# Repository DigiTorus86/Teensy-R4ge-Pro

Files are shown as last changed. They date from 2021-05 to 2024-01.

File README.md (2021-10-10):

# Teensy-R4ge-Pro
<p>
Software and resources for the Teensy R4ge Pro custom game platform. See documents folder for schematic.  
</p>

<p>
Harness the power of the 600MHz ARM Cortex M-7 that powers the Teensy 4.1 with flexible controls, a large display, CD-quality sound input and output.  Runs a variety of emulators for a retro-tastic mobile arcade experience.  Works as a high-fidelity sound generating and processing platform.  Includes a 10dB booster circuit with gain control, suitable for applying digital effects to a variety of audio input sources - including electric guitars.  
</p>

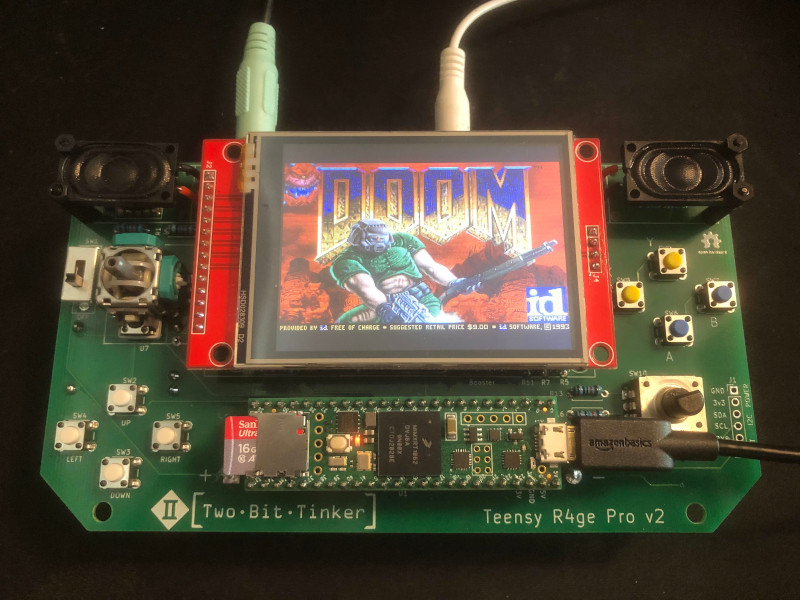
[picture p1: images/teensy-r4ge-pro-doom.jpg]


<h3>Key Components/Requirements</h3>
<p>
- Custom PCB, bread board, or protoboard.  See the gerbers folder or order from https://www.pcbway.com/project/shareproject/Teensy_4_1_R4ge_Pro_Mobile_Platform.html <br>
- Teensy 4.1<br>
- ILI9341 320x240 TFT with touch screen<br>
- Analog joystick<br>
- Rotary encoder<br>
- PCM5102a I2S DAC w/headphone jack<br>
- PAM8403 amplifier and 8 Ohm/1W speakers and/or powered external speakers w/3.5mm jack<br>
- PCM1802 I2S Stereo ADC<br>
- TL072 OpAmp<br>
- 8 MB PSRAM, SD card, and USB host cable for Teensy strongly recommended, as these are required to run different platform emulators<br>
- Some sketches have additional hardware requirements (components attached to I2C or Serial pins, or SD card)<br>
- See BOM file in the documents folder for full list of components.<br>
- STL file for printing a simple case also included in the documents folder.<br>
</p>

<p>
  Runs Doom and the other MCUME emulators by Jean MarcHarvengt.    https://github.com/Jean-MarcHarvengt/MCUME
  Requires minor config and IO pin mapping changes, as well as 8MB PSRAM and an SD card.  
</p>

<h3>App Descriptions</h3>
<p>
  - Test:   Exercises all the hardware on the board to verify operation and calibration. <br/>
  - Gravitack: Classic vector space shooter. (Port from original ESP32 Conference Badge)  <br/>
  - Tombstone: Port of the classic TI-99/4A game.  <br/>
  - Synth:  A graphical 4-operator/4-voice FM synth, playable via on-screen keyboard + stylus, 8 step sequencer, or MIDI input on the RX8 pin.<br/>
</p>

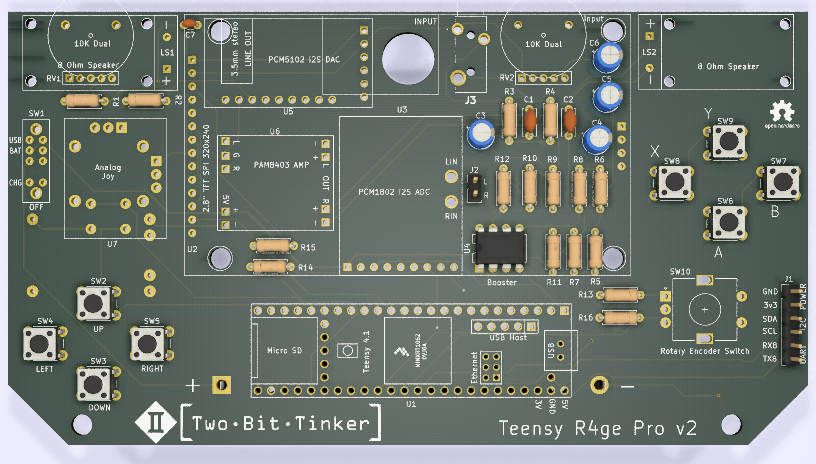
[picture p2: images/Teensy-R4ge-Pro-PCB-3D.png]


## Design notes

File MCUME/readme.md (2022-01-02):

### Using MCUME on the Teensy R4ge Pro

1. Install the 8MB PSRAM chip on the bottom of your Teensy 4.1.  Purchase link, instructions, and test app can be found at https://www.pjrc.com/store/psram.html 
2. Make sure you have a FAT32 formatted micro SD available.
3. Having the USB pins soldered to the Teensy and hooked up to a USB keyboard is very helpful as some games/options require keyboard input to proceed.  Can purchase the USB host cable from https://www.pjrc.com/store/cable_usb_host_t36.html   
3. Clone the MCUME repo: https://github.com/Jean-MarcHarvengt/MCUME/ 
4. Create the directories in the root of the SD card for the emulator ROM files and copy your ROM files to them.  Place the microSD in the Teensy's built-in SD card slot.
5. Copy the iopins.h and platform_config.h files from the Teensy-R4ge-Pro folders (or copy/paste the settings) to set the correct hardware configuration for each emulator.
6. Load the sketch for the emulator you want to run into the Arduino IDE.
7. Select Tools->Optimize and choose the appropriate option based on the emulator.
    - Doom:  Faster
    - Castaway/Atari ST:  Smallest Code
    - NES/Nofrendo:  Faster
    - UAE/Amiga:  Smallest Code
  
8. Compile and load the sketch to the Teensy.  If it works, you should see the game/emulator screen and be able to select from the list of detected ROMs that you loaded to the microSD. 

## Troubleshooting
- If compilation fails and exceeds available memory, try optimizing for Smallest Code
- If compiling on Mac or Linux, may need to fix some include file capitalization errors in MCUME (i.e. in tft_t_dma.cpp).
- Verify that the PSRAM is installed and working using the Teensy example sketch
- Hookup a keyboard to the Teensy USB pins and try different keypresses if screen appears frozen
- Try loading different ROMs.  Quite a few of the tested ROMs failed to work.
- Try the latest code from the MCUME repo or the included emulator code in this repo.

## Teensy R4ge Pro GPIO Pin Assignments

Full list of GIP pin assignments can be found in the ```teensy_r4ge_pro.h``` file in the Arduino IDE test sketch or any of the PlatformIO ```include``` folders.

- TFT_DC     9  // Data (high)/Command (low) pin
- TFT_CS    10  // SPI Chip Select pin for screen (active low)
- TFT_RST  255  // Reset pin NOT USED, connected to 3V3 (always high)
- TFT_MISO  12  // SPI Master In Slave Out
- TFT_MOSI  11  // SPI Master Out Slave In
- TFT_CLK   13  // SPI Clock
- TFT_LED  255  // TFT LED brightness control, connected to 3V3
- TCH_CS    37  // SPI Touch controller Chip Select (active low)
- SD_CS     BUILTIN_SDCARD  // (254) SPI SD card reader Chip Select pin

- JOYX_L    16  // Left analog joystick X axis
- JOYY_L    17  // Left analog joystick Y axis
- JBTN_L    25  // Left joystick button

- ENC_BTN  24  // Rotary encoder button/switch

- BTN_Y     5
- BTN_X     4
- BTN_B     3
- BTN_A     2
- BTN_RIGHT 32
- BTN_LEFT  31
- BTN_DOWN  30
- BTN_UP    29

Teensy 4.1 I2C Pins 
- SDA       18
- SCL       19

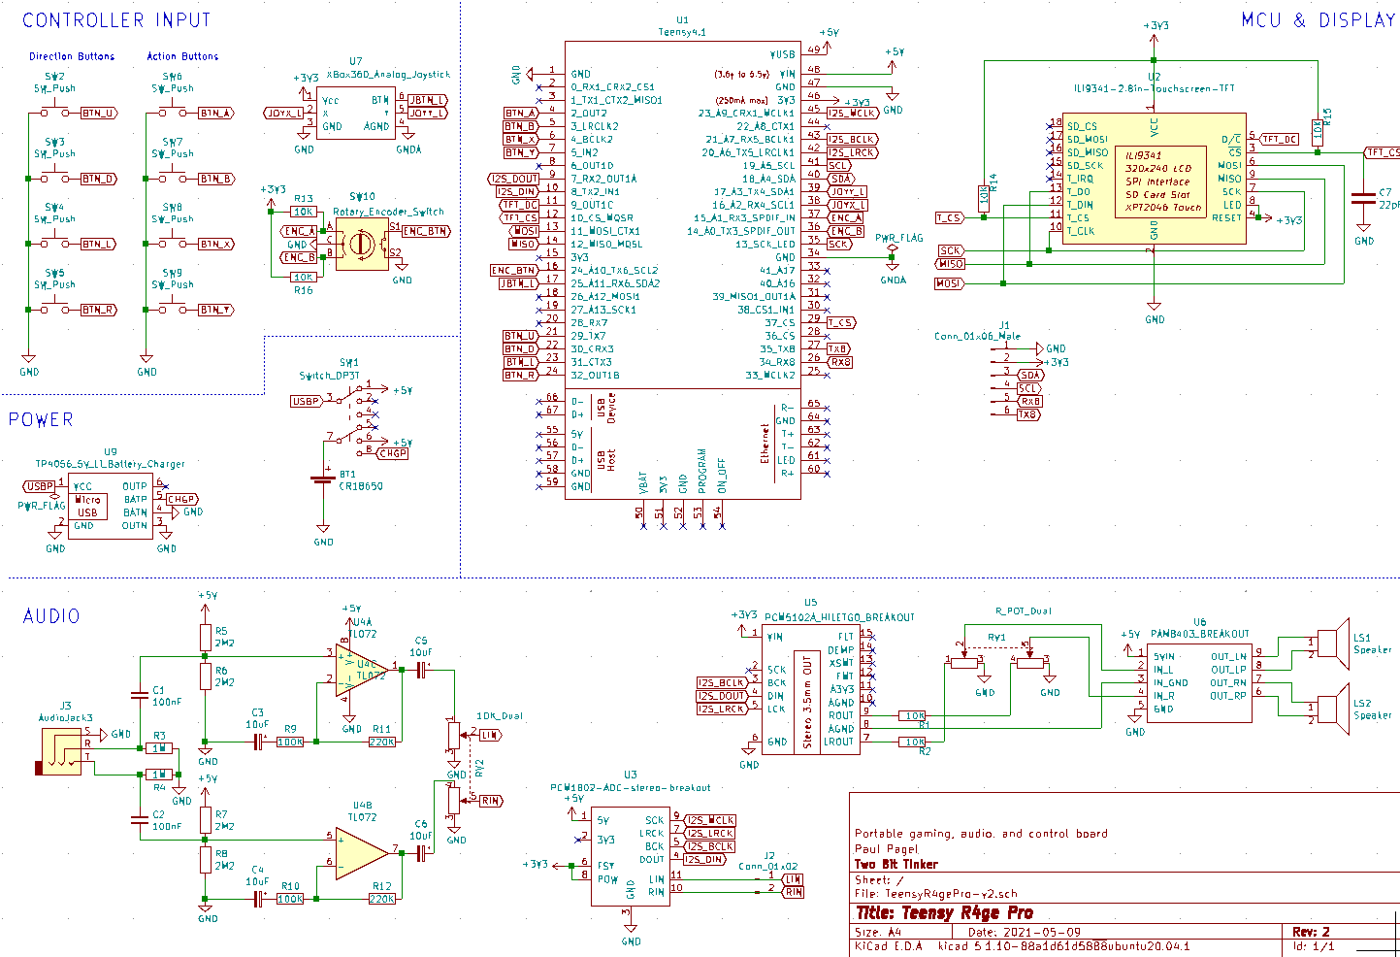
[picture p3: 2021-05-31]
images/Teensy-R4ge-Pro-schematic.png

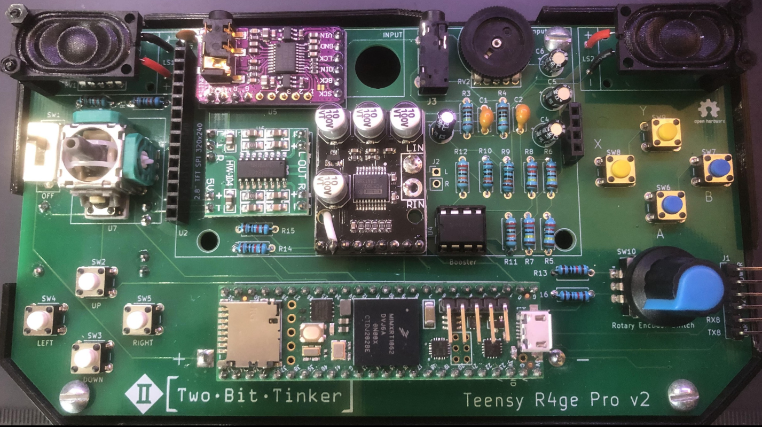
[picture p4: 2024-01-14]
images/Teensy-R4ge-Pro-no-screen.png

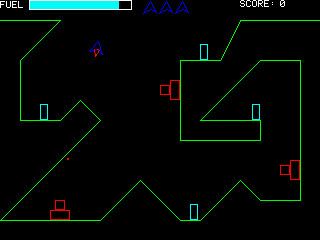
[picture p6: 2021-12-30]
images/Gravitack-L6.jpg

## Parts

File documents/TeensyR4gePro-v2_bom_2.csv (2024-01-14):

Component | Description | Part | References | Value | Footprint | Quantity Per PCB | Datasheet
1 | Single-cell battery | Battery_Cell | BT1 | CR18650 | BatteryHolder_MPD_BH-18650-PC2-no-holes | 1 | ~
2 | Unpolarized capacitor, small symbol | C_Small | C1 C2 | 100nF | C_Disc_D5.0mm_W2.5mm_P5.00mm | 2 | ~
3 | Polarized capacitor, small symbol | CP_Small | C3 C4 C5 C6 | 10uF | CP_Radial_D5.0mm_P2.50mm | 4 | ~
4 | Unpolarized capacitor | C | C7 | 22pF | C_Disc_D3.0mm_W1.6mm_P2.50mm | 1 | ~
5 | Audio Jack, 3 Poles (Stereo / TRS) | AudioJack3 | J3 | AudioJack3 | STX35013N | 1 | ~
6 | Generic connector, single row, 01x02, script generated (kicad-library-utils/schlib/autogen/connector/) | Conn_01x02_Male | J2 | Conn_01x02 | PinHeader_1x02_P2.54mm_Vertical | 1 | ~
7 | Generic connector, single row, 01x06, script generated (kicad-library-utils/schlib/autogen/connector/) | Conn_01x06_Male | J1 | Conn_01x06_Male | PinHeader_1x06_P2.54mm_Vertical | 1 | ~
8 | Speaker | Speaker | LS1 LS2 | Speaker | Speaker_Visaton_K14.25_8_ohm | 2 | ~
9 | Resistor | R | R9 R10 | 100K | R_Axial_DIN0207_L6.3mm_D2.5mm_P7.62mm_Horizontal | 2 | ~
10 | Resistor | R | R1 R2 R13 R14 R15 R16 | 10K | R_Axial_DIN0207_L6.3mm_D2.5mm_P7.62mm_Horizontal | 6 | ~
11 | Resistor | R | R3 R4 | 1M | R_Axial_DIN0207_L6.3mm_D2.5mm_P7.62mm_Horizontal | 2 | ~
12 | Resistor | R | R11 R12 | 220K | R_Axial_DIN0207_L6.3mm_D2.5mm_P7.62mm_Horizontal | 2 | ~
13 | Resistor | R | R5 R6 R7 R8 | 2M2 | R_Axial_DIN0207_L6.3mm_D2.5mm_P7.62mm_Horizontal | 4 | ~
14 |  | R_POT_Dual-MyMCU_Espressif | RV2 | 1OK_Dual | Potentiometer_10K_Dual_Uxcell | 1 | ~
15 |  | R_POT_Dual-MyMCU_Espressif | RV1 | R_POT_Dual | Potentiometer_10K_Dual_Uxcell | 1 | ~
16 | Rotary encoder, dual channel, incremental quadrate outputs, with switch | Rotary_Encoder_Switch | SW10 | Rotary_Encoder_Switch | RotaryEncoder_Alps_EC11E-Switch_Vertical_H20mm | 1 | ~
17 | Push button switch, generic, two pins | SW_Push | SW2 SW3 SW4 SW5 SW6 SW7 SW8 SW9 | SW_Push | SW_PUSH_6mm | 8 | ~
18 |  | Switch_DP3T | SW1 | Switch_DP3T | Switch_DP3T_CK_OS203011MS1QP1 | 1
19 |  | ILI9341-2.8in-Touchscreen-TFT-MyMCU_Espressif | U2 | ILI9341-2.8in-Touchscreen-TFT | ILI9341_2.8_TFT_TOUCH_SD_SPI | 1 | http://pan.baidu.com/s/11Y990
20 |  | PAM8403_BREAKOUT-MyMCU_Espressif | U6 | PAM8403_BREAKOUT | PAM8403_Breakout_HW104 | 1
21 |  | PCM1802-ADC-stereo-breakout | U3 | PCM1802-ADC-stereo-breakout | PCM1802-ADC-breakout | 1
22 |  | PCM5102A_HILETGO_BREAKOUT-MyMCU_Espressif | U5 | PCM5102A_HILETGO_BREAKOUT | PCM5102A_Hiletgo_Breakout | 1
23 | Dual Low-Noise JFET-Input Operational Amplifiers, DIP-8/SOIC-8 | TL072 | U4 | TL072 | DIP-8_W7.62mm | 1 | http://www.ti.com/lit/ds/symlink/tl071.pdf
24 |  | TP4056_5V_Li_Battery_Charger | U9 | TP4056_5V_Li_Battery_Charger | TP4056_Li_Battery_Charger_Breakout | 1
25 |  | Teensy4.1 | U1 | Teensy4.1 | Teensy41 | 1
26 |  | XBox360_Analog_Joystick-MyMCU_Espressif | U7 | XBox360_Analog_Joystick | XBox360_Analog_Joystick | 1
Component Groups: | 26
Component Count: | 49
Fitted Components: | 49
Number of PCBs: | 1
Total components: | 49
Schematic Version: | 2
Schematic Date: | 2021-05-09
PCB Variant: | [u'default']
BoM Date: | Sun 16 May 2021 08:42:20 AM EDT
Schematic Source: | /home/digitorus/KiCad/Teensy41_R4ge_Pro_Encoder/TeensyR4gePro-v1/TeensyR4gePro-v2.sch
KiCad Version: | Eeschema 5.1.9-73d0e3b20d~88~ubuntu20.04.1

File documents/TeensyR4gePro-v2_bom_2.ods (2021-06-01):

Component | Description | Part | References | Value | Footprint | Quantity Per PCB | Price Each | Extended Price | Availability | Order URL
1 | Single-cell battery | Battery_Cell | BT1 | CR18650 | BatteryHolder_MPD_BH-18650-PC2-no-holes | 1 | $1.25 | $1.25 | Good | https://www.amazon.com/gp/product/B07D1FRL54
2 | Unpolarized ceramic capacitor, small symbol | C_Small | C1 C2 | 100nF | C_Disc_D5.0mm_W2.5mm_P5.00mm | 2 | $0.06 | $0.12 |  | https://www.amazon.com/dp/B08B3VCK42
3 | Polarized electrolytic capacitor, small symbol | CP_Small | C3 C4 C5 C6 | 10uF | CP_Radial_D5.0mm_P2.50mm | 4 | $0.19 | $0.76 |  | https://www.mouser.com/ProductDetail/667-ECA-1EM100I
4 | Unpolarized ceramic capacitor | C | C7 | 22pF | C_Disc_D3.0mm_W1.6mm_P2.50mm | 1 | $0.18 | $0.18 |  | https://www.mouser.com/ProductDetail/Vishay/1C10C0G220J050B?qs=%2FVYrxewl4mYopKLzL8PbyA%3D%3D
5 | Audio Jack, 3 Poles (Stereo / TRS) | AudioJack3 | J3 | AudioJack3 | Kycon STX35013N | 1 | $1.07 | $1.07 | Good | https://www.mouser.com/ProductDetail/806-STX-3501-3N
6 | Generic connector, single row, 01x02, script generated (kicad-library-utils/schlib/autogen/connector/) | Conn_01x02_Male | J2 | Conn_01x02 | PinHeader_1x02_P2.54mm_Vertical | 1 | $0.40 | $0.40 | Good | https://www.amazon.com/MCIGICM-Header-2-45mm-Arduino-Connector/dp/B07PKKY8BX
7 | Generic connector, single row, 01x06, script generated (kicad-library-utils/schlib/autogen/connector/) | Conn_01x06_Male | J1 | Conn_01x06_Male | PinHeader_1x06_P2.54mm_Vertical | 1 | $0.40 | $0.40 | Good | https://www.amazon.com/MCIGICM-Header-2-45mm-Arduino-Connector/dp/B07PKKY8BX
8 | Speaker, 8 Ohm | Speaker | LS1 LS2 | Speaker | Speaker_Visaton_K14.25_8_ohm | 2 | $4.65 | $9.30 | Fair | https://www.mouser.com/ProductDetail/243-K14.25-8OHM
9 | Resistor ¼ Watt | R | R9 R10 | 100K | R_Axial_DIN0207_L6.3mm_D2.5mm_P7.62mm_Horizontal | 2 | $0.05 | $0.10 |  | https://www.amazon.com/EDGELEC-Resistor-Tolerance-Resistance-Optional/dp/B07HDG9K8P
10 | Resistor ¼ Watt | R | R1 R2 R13 R14 R15 R16 | 10K | R_Axial_DIN0207_L6.3mm_D2.5mm_P7.62mm_Horizontal | 6 | $0.05 | $0.30 |  | https://www.amazon.com/EDGELEC-Resistor-Tolerance-Resistance-Optional/dp/B07HDGX5LM
11 | Resistor ¼ Watt | R | R3 R4 | 1M | R_Axial_DIN0207_L6.3mm_D2.5mm_P7.62mm_Horizontal | 2 | $0.05 | $0.10 |  | https://www.amazon.com/EDGELEC-Resistor-Tolerance-Resistance-Optional/dp/B07HDFVM49
12 | Resistor ¼ Watt | R | R11 R12 | 220K | R_Axial_DIN0207_L6.3mm_D2.5mm_P7.62mm_Horizontal | 2 | $0.05 | $0.10 |  | https://www.amazon.com/EDGELEC-Resistor-Tolerance-Resistance-Optional/dp/B07HDFTX3P/ref=sr_1_2_sspa
13 | Resistor ¼ Watt | R | R5 R6 R7 R8 | 2M or 2M2 | R_Axial_DIN0207_L6.3mm_D2.5mm_P7.62mm_Horizontal | 4 | $0.05 | $0.20 |  | https://www.amazon.com/EDGELEC-Resistor-Tolerance-Resistance-Optional/dp/B07HDGLLJC
14 | Potentiometer, dual 10K | R_POT_Dual | RV2 | 1OK_Dual | Potentiometer_10K_Dual_Uxcell | 1 | $0.50 | $0.50 | Good | https://www.amazon.com/Uxcell-5-Pin-Linear-Potentiometer-16mmx3/dp/B013FPKCMM
15 | Potentiometer, dual 10K | R_POT_Dual | RV1 | R_POT_Dual | Potentiometer_10K_Dual_Uxcell | 1 | $0.50 | $0.50 | Good | https://www.amazon.com/Uxcell-5-Pin-Linear-Potentiometer-16mmx3/dp/B013FPKCMM
16 | Rotary encoder, dual channel, incremental quadrate outputs, with switch, Bourns/Alps | Rotary_Encoder_Switch | SW10 | Rotary_Encoder_Switch | RotaryEncoder_Alps_EC11E-Switch_Vertical_H20mm | 1 | $1.14 | $1.14 | Good | https://www.mouser.com/ProductDetail/652-PEC12R4015FS0024
17 | Push button switch, generic, two pins | SW_Push | SW2 SW3 SW4 SW5 SW6 SW7 SW8 SW9 | SW_Push | SW_PUSH_6mm | 8 | $0.10 | $0.80 | Good | https://www.amazon.com/gp/product/B07C7211PJ
18 | DP3T Power switch | Switch_DP3T | SW1 | Switch_DP3T | Switch_DP3T_CK_OS203011MS1QP1 | 1 | $0.60 | $0.60 | Good | https://www.mouser.com/ProductDetail/611-OS203011MV9QN1
19 | TFT Display | ILI9341-2.8in-Touchscreen-TFT | U2 | ILI9341-2.8in-Touchscreen-TFT | ILI9341_2.8_TFT_TOUCH_SD_SPI | 1 | $17.59 | $17.59 | Good | https://www.amazon.com/gp/product/B073R7BH1B
20 | Stereo Amplifier | PAM8403_BREAKOUT-MyMCU_Espressif | U6 | PAM8403_BREAKOUT | PAM8403_Breakout_HW104 | 1 | $1.10 | $1.10 | Good | https://www.amazon.com/gp/product/B00LODGV64
21 | Stereo ADC | PCM1802-ADC-stereo-breakout | U3 | PCM1802-ADC-stereo-breakout | PCM1802-ADC-breakout | 1 | $11.59 | $11.59 | Good | https://www.amazon.com/Anncus-%E3%80%90Simple-Robot%E3%80%91PCM1802-Verstarker-Analog-INPU/dp/B095N99LKK (https://www.amazon.com/Anncus-【Simple-Robot】PCM1802-Verstarker-Analog-INPU/dp/B095N99LKK/ref=sr_1_5)
22 | Stereo DAC | PCM5102A_HILETGO_BREAKOUT | U5 | PCM5102A_HILETGO_BREAKOUT | PCM5102A_Hiletgo_Breakout | 1 | $10.19 | $10.19 | Good | https://www.amazon.com/HiLetgo-Lossless-Digital-Converter-Raspberry/dp/B07Q9K5MT8
23 | Dual Low-Noise JFET-Input Operational Amplifiers, DIP-8 | TL072 | U4 | TL072 | DIP-8_W7.62mm | 1 | $0.75 | $0.75 | Good | https://www.mouser.com/ProductDetail/Texas-Instruments/TL072IP?qs=5BZzbFV4k2v7IBrcArRPQw%3D%3D
24 | Battery Charger | TP4056_5V_Li_Battery_Charger | U9 | TP4056_5V_Li_Battery_Charger | TP4056_Li_Battery_Charger_Breakout | 1 | $1.00 | $1.00 | Good | https://www.amazon.com/gp/product/B071RG4YWM
25 | Teensy 4.1 Microcontroller board | Teensy4.1 | U1 | Teensy4.1 | Teensy41 | 1 | $26.85 | $26.85 | OOS until July | https://www.pjrc.com/store/teensy41.html
26 | Analog joystick with button | XBox360_Analog_Joystick | U7 | XBox360_Analog_Joystick | XBox360_Analog_Joystick | 1 | 1.75 | $1.75 | Good | https://www.amazon.com/dp/B07NM7GW91
 | Generic 2.54mm female header connectors |  |  |  | Female header pins 2.54mm | 2 | $0.80 | $1.60 | Good | https://www.amazon.com/Haobase-2-54mm-Straight-Single-Headers/dp/B01DLX6RSQ
 |  |  |  |  |  |  | Subtotal | $90.24
 |  |  | Additional Recommended Items
 |  |  | microSD card (8-16GB) |  |  | 1 | $5.00 | $5.00 | Good | https://www.amazon.com/PNY-microSDHC-Memory-2-Pack-P-SDU16GX2U185GW-GE/dp/B07TDN2G18
 |  |  | Teensy USB Host cable |  |  | 1 | $3.00 | $3.00 | Good | https://www.pjrc.com/store/cable_usb_host_t36.html
 |  |  | 8 MB PSRAM |  |  | 1 | $1.80 | $1.80 | Good | https://www.pjrc.com/store/psram.html
 |  |  |  |  |  |  | With Recommended: | $100.04

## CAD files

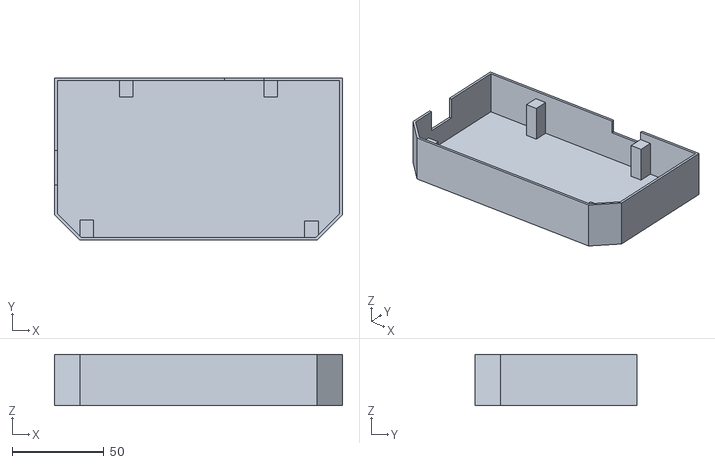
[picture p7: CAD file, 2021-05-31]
documents/Rage_Pro_Case3.stl
156.8 x 88.4 x 28.0

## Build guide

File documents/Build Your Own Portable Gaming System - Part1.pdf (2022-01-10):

# Build Your Own Portable Gaming System

Paul Pagel

### Build Your Own Portable Gaming System

Sign in at the table to receive your hardware kit and parts list
- Take a red cup if you’re pretty new to PCBs and soldering (or it’s been a while)
- Take a blue cup if you’re experienced with electronics and/or soldering
- If possible, sit next to someone with a different colored cup than your own
- Please do NOT turn on soldering irons or begin assembly yet.

If you have not already done so:
- Download the pre-requisites instructions and complete all downloads and installations
- http://prereqs.codemash.org/

Slide deck download (PDF): https://github.com/DigiTorus86/Teensy-R4ge-Pro/tree/master/documents

# Welcome!

## About Me

- “Crusty Veteran” and long-time CodeMash attendee
- 20+ years of developing software professionally
and managing software teams
- Application Architect for Domino’s Technology team
- Particular area of electronic/hardware interest = Audio & Video
- Email: pjpagel86@gmail.com
- Blog: twobittinker.com

## Schedule for the Day

Morning: Hardware

LUNCH!

Afternoon: Software

## Session Objectives

Learn/review the basics of setting up and working with electronics and microcontrollers:
- Terminology
- Schematics and pinouts
- Soldering and assembly techniques
- Testing and troubleshooting hardware

Build and test a working portable game system!

HAVE FUN!!

## Session Guidelines

- This is an interactive workshop. Be an active participant.
- If I ask a question to the group, go ahead and call out the answer.
- If you have a question, raise you hand…the sooner the better.
- Acronyms and abbreviations - now in nested varieties...
- Don’t suffer in silence.
- Work with the session assistants and participants around you during the assembly and testing process. Leverage the wisdom of teams.
- Be respectful of your fellow attendees and keep side conversations to a minimum during the lecture portions.

# The R4ge Pro System

Begin with the End in Mind

## Remember Me?

CodeMash 2020 badge
Based on ESP32

## Teensy R4ge Pro

+ Bigger screen
+ Faster controller
+ More controls
+ Way better audio
- No WiFi or BLE
- Less battery life

## The Tester App

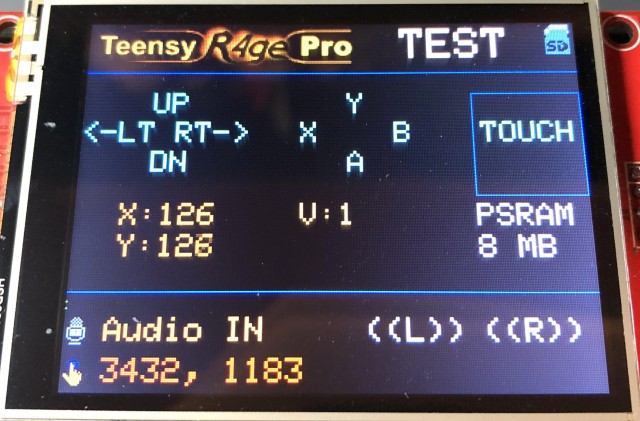
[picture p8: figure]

Allows you to easily exercise all the buttons and
peripherals on the board and detect any problems.
Comes pre-loaded onto the
microcontroller included in the kits.
Should be the first thing you see on powering up.

## Microcontrollers

- Microcontroller: A small computer on a single integrated circuit often used in embedded applications. Also referred to as a Micro Control Unit or MCU.
- A few common examples:
- Atmel AVR
- ARM Cortex M-series
- ESP8266 / ESP32-Wroom-32
- Come in a number of form factors
- Dual Inline Package (DIP)
- Surface Mount Devices (SMD)

## Development Boards

Development Boards are designed to make the MCU easier to evaluate and to use in small scale custom designs.

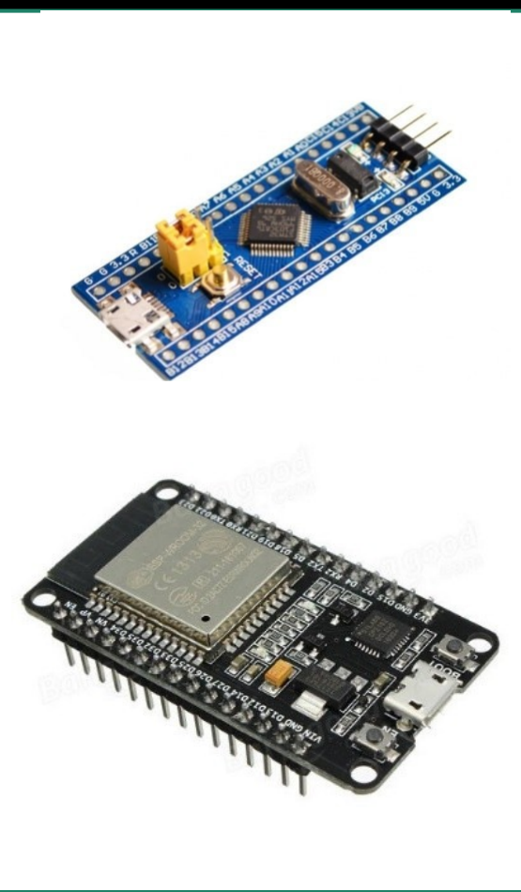
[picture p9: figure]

Common examples:
- Arduino Uno
- Adafruit Feather
- STM32F103 “Blue Pill”
- ESP32 Dev Kit
- Teensy

## Meet the Teensy 4.1

- NXP ARM Cortex M7 running @ 600 MHz
- 8 MB Flash, 1 MB RAM + 2 expansion locations
- Micro SD card port
- 55 digital input/output pins
- USB device and USB host
- https://www.pjrc.com/store/teensy41.html

Source: https://protosupplies.com/product/teensy-4-1/?add-to-cart=7010

## Teensy 4.1 Pinout

# Electronic Components

What’s in the Kit and What It Does

## Teensy 4.1

Powerful microcontroller development board that is the heart and soul of our game system.

Be very careful to put this into the board the correct way, with the SD card on the left and the USB port on the right!

In Kit:

- 1 Teensy 4.1

## PSRAM

Pseudostatic RAM external volatile memory chip.

Note the dimple indicating pin 1.
Orientation will be critical.

In Kit:

- 1 – 8MB PSRAM
IC

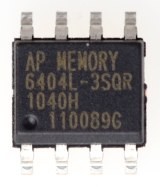
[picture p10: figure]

## Printed Circuit Board (PCB)

- Contains attachment points/through-holes
for components and wiring traces to them.
- Silk screen identifies the location and orientation for components to be soldered.
- Allows for quicker assembly, fewer mistakes, and smaller footprint compared to a proto or strip board.

In Kit:

- 1 custom PCB
(v2)

## PCB Structures

Solder Mask
- Top layer that repels solder and protects the traces

Traces
- Copper wires that connect the solder pads and rings
- The PCB has 2 layers of traces (front and back)
- Traces can be damaged

## PCB Structures

Through Holes
- Component holes: sized to accommodate component wires (~22 gauge) and always have an annular ring for soldering.
- Mounting holes: various sizes, may or may not have metallic annular rings. Used to connect cases, standoffs, peripherals, etc.
- Vias: smaller holes that allow the traces to carry current from one layer to another. Not for soldering!

## PCB Structures

Surface Mount
- Solder pads: used to connect the leads and pads on surface mount device (SMD) components to the PCB
- Solder bridge: two small squarish pads close to each other designed to be connected by a single blob of solder, wire, or 0R resistor. Operates like a semi-permanent dip switch.

## Resistors

Passive device used reduce current or divide voltages
- Non-polarized (no right or wrong orientation)
- Rated by % tolerance to named value and power capacity
- Example: 1% tolerance and ¼ watt
- Measured in Ohms
- 220R indicates 220 Ohms
- 10K indicates 10,000 Ohms
- 2M indicates 2,000,000

In Kit:
- 6 – 10K
brown-black-black-red
- 2 – 100K
brown-black-black-orange
- 2 – 200K
red-red-black-orange
- 2 – 1M
brown-black-black-yellow
- 4 – 2M
red-black-black-yellow

## Breaking the Code

Many mnemonics
available. One
example:
Bright Boys Rave Over
Young Girls But Veto
Getting Wed

When in doubt,
measure with a
multimeter.

## Capacitors

Passive devices that store electrical energy Some types are polarized, others are not
- Ceramic = non-polarized
- Electrolytic = polarized
Measured in Farads
- uF = micro Farads (1 millionth)
- nF = nano Farads (1 billionth)
- pF = pico Farads (1 trillionth)

•

In Kit:

- 2 – 100nF ceramic, marked “104” [C1, C2]
- 4 – 10uF electrolytic [C3-C6]
- 1 – 22pF ceramic, marked “22” [C7]

## Buttons and Switches

Mechanical devices for opening and closing a circuit
- Momentary vs. Latching
- Normally Open (NO) vs. Normally Closed (NC)
- Poles = number of circuits connected
- Throw = number of positions (on/off is single)

DP3T – Double Pole
Triple Throw

Tactile momentary
NO button
(Normally Open)

In Kit:

- 1 – Dual Pole 3-Throw [SW1]
- 8 – momentary NO buttons [SW2 - 9]

## TFT LCD Screen

Thin Film Transistor (TFT) Liquid Crystal Display (LCD)
- Usually have a specific control chip, i.e. ILI9341
- Often include an SD card reader on the back
- May or may not have touch capability (T_ pins)
- Often use Serial Peripheral Interface (SPI) protocol for communication with the MCU

In Kit:

- 1 – TFT LCD, 2.8” 320x240 w/integrated ILI9341 SPI
controller, 3.3v, 262K colors [U2]

## Micro SD Card

Secure Digital Memory Card
- Used for non-volatile storage
- Come in a variety of sizes and speeds
- Can only be inserted 1 way due to shape

In Kit:

- 1 –16GB micro SD card

## 18650 Lithium Battery

### 3.7 v lithium rechargeable battery, commonly

used in flashlights and vaping gear
- 18650 indicates 18mm diameter x 65mm height
- Voltage output range is 4.2v – 2.5v, which pairs nicely with 3.3v MCUs
- Capacity is measured in mAh (milliamp hours) and maximum continuous discharge in Amperes.
- These are inversely related. Generally favor capacity for MCUs.

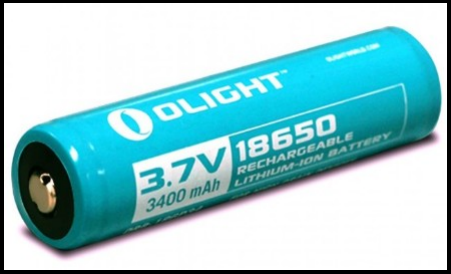
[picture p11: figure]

In Kit:

- Batteries not included* :-( Victim of supply chain woes

## Battery Holder

Holds battery in place and provides electrical connection between battery and circuit board.

Polarized – pay close attention to + / -

Battery fit may be a bit tight. Recommend looping some ribbon or tape around battery to ease extraction.

In Kit:

- 1 – 18650 battery holder [BT1]

## Battery Charger

5V 1A micro USB board for charging CR18650 batteries

- Allows charging without having to remove the battery from the board.
- Red LED indicates charging.
- Blue LED indicates charged or powering
board directly. | In Kit:
| • 1 – TP4056 battery charger [U9]

## Digital to Analog Converter

Takes digital audio data and converts it to
analog waveform output
- Uses the Inter IC Sound (I2S) protocol.
- Support multiple sampling rates and bit
depths.
- No built-in amplification or volume control. | In Kit:
| • 1 – PCM5102A DAC stereo breakout board

## Audio Amplifier

Takes low-voltage analog output and amplifies it

Amplification is limited by the power rating
(watts)
Can be mono or stereo | In Kit: • 1 – PAM8403 2x3W class D stereo amplifier breakout board

## Analog to Digital Converter

Takes analog input voltage and converts it
to digital data
- Uses the Inter IC Sound (I2S) protocol.
- Support multiple sampling rates and bit depths.
- Most breakouts of this model have a board error where the configuration solder bridge is not connected to power.

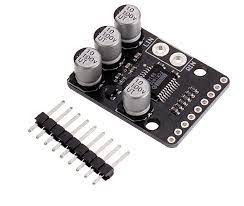
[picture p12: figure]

In Kit:

- 1 – PCM1802 ADC
breakout board

## Potentiometers

Variable resistors

- Can be rotary (dial/thumbwheel) or linear (slide)
- Can be single or multi-channel
- Can have linear or logarithmic resistance
tapers | In Kit:
| • 2 – 50K stereo potentiometers*

## Analog Joystick

Provides 2-axis control with variable output

- Consists of two potentiometers, one for the X-axis and one for the Y-axis.
- Must be read using an Analog to Digital Converter (ADC)
- Often incorporates a button that is activated by pushing down on the joystick
- Commonly used in game console controllers

In Kit:

- 1 – Analog joystick with integrated button

## Rotary Encoder

Knob that can be rotated indefinitely to provide numerical values

- Contains 2 pins that are used to determine what direction the knob is turned.
- Unlike a potentiometer, has no intrinsic state or value.
- Often incorporates a button that is activated by pushing down on the knob.
- May or may not click when turned.

In Kit:

- 1 – Rotary encoder
- 1 – Encoder cap

## Audio Jack

Standard TRS stereo audio connector
- Tip: Left channel
- Ring: Right channel
- Sleeve: Ground
- Also come in TS (mono) varieties
- May or may not be switched
- Usually 3.5mm (1/8”) or 1/4” sizes

In Kit:

- 1 – 3.5mm stereo
jack

## Operational Amplifier

Multipurpose voltage amplifier integrated circuit (IC)
- Used in a huge variety of applications
- Always consists of
- Inverting input (in-)
- Non-inverting input (in+)
- Output (Vout)
- Pip on top indicates pin #1
- Pins are sharp and
bend easily

In Kit:

- 1 – TL072 OpAmp

## IC Sockets

Allow ICs to be removed without soldering

- One end will always have a notch indicating the end for Pin #1
- Inserting the IC takes a little finesse
- Optional, but strongly recommended

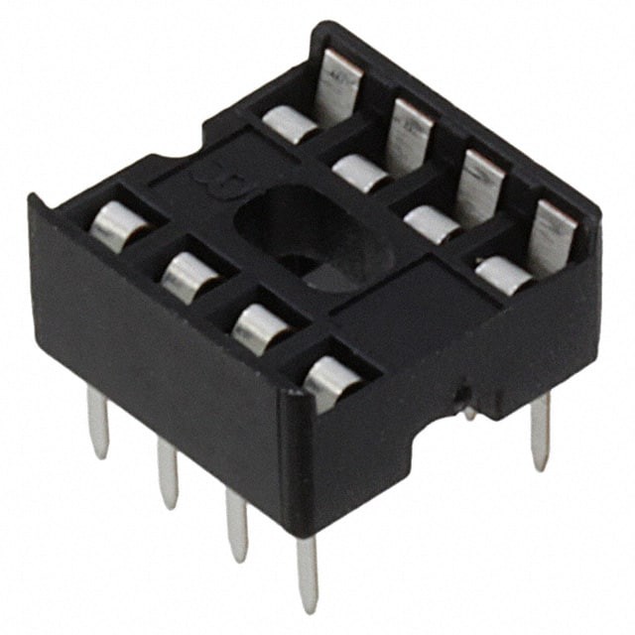
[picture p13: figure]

- Use IC puller to remove ICs! | In Kit:
| • 1 – 8 pin socket for TL072 OpAmp

## Speakers

Convert analog AC signals to audio

- Rated by impedance (Ohms) and power (Watts)
- Smaller speakers produce higher
frequencies
- Bigger speakers produce lower frequencies | In Kit:
| • 2 – 8 ohm 1W speakers

## Header Pins

Connect controllers, breakout boards, major components, and jumpers

- Come in male and female varieties.
- Additional common characteristics
- normal height or extended (stacking) height
- straight or right-angled
- single row or double row

In Kit:

- Female header pins
- Male header pins

## Standoffs

Connect components, PCBs, and cases

- Come in various lengths and thicknesses
- Usually hexagonal
- May be plastic/nylon or brass

In Kit:

- 4 – nylon M2 standoffs,
screws, and nuts

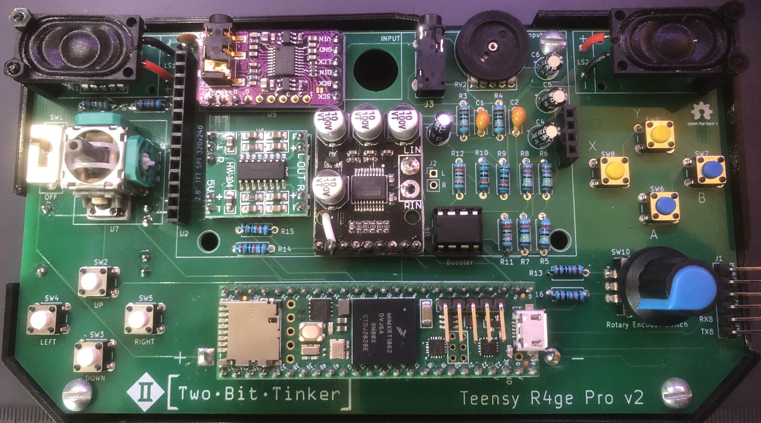
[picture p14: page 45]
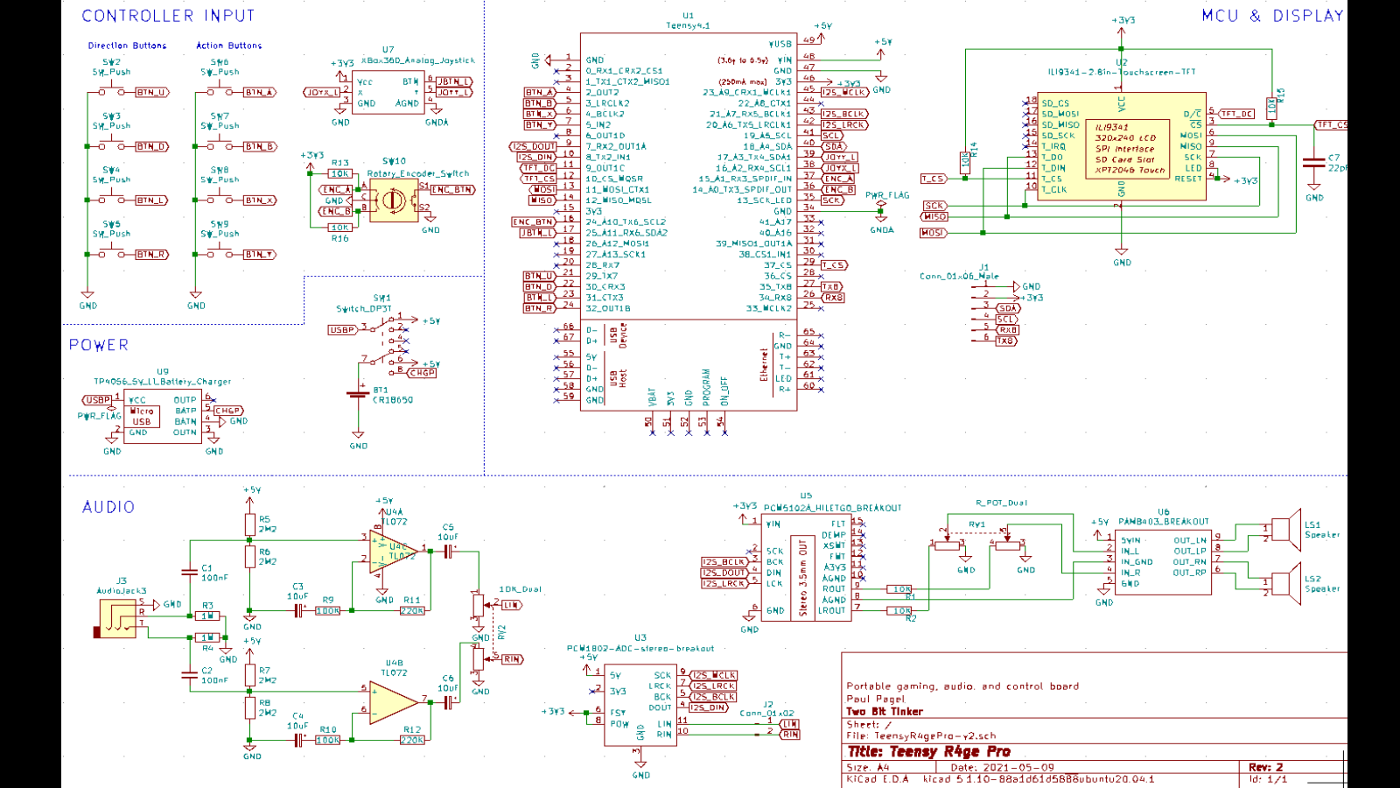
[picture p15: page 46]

## Matching the Schematic to the PCB

- The schematic can help identify the role of each component on the PCB.
- Component identifiers on the schematic match up to those on the PCB and BOM (Bill of Materials)
- SW1 = Switch1, R1 = Resistor1, C1 = Capacitor1, etc.
- Schematic circuit is easier to follow than the traces on the PCB and is useful for diagnosing problems or determining if a substitute component can be used.
- The physical pin layout on the PCB will usually be different from the logical pin layout on the schematic.

https://github.com/DigiTorus86/Teensy-R4ge-Pro (documents folder)

# Soldering

Bringing the Heat Without Getting Burned

## Ummm...No

## Soldering Iron

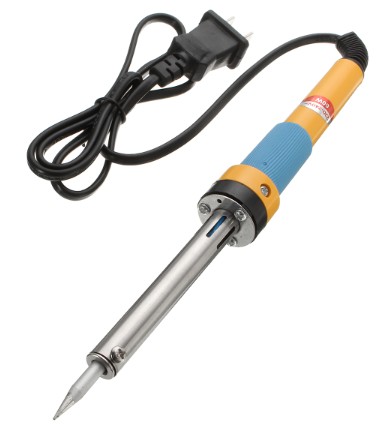
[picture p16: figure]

- Tip needs to heat up to about 700F / 370C before use.
- Keep the tip lightly tinned (shiny) but not gobbed with solder.
- Use the scouring pad to remove excess solder from the tip.
- Safety:
- Only pick up by the handle
- Practice good tip control at all times - no balancing, waving, or gesturing with the iron. It’s not a wand.
- Keep cords clear of obstacles
- Don’t set down on table – always use the provided stand
- Don’t hand it to another person. Let them pick it up.
- Turn the iron off/unplug before leaving your station

## Solder

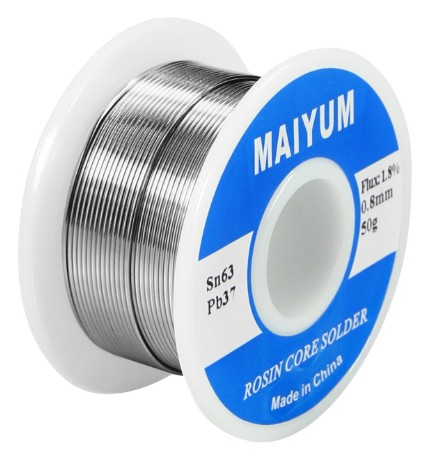
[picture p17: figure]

- Most common solder for hand-soldering is a mix of tin (~60%) and lead (~40%)
- Rosin core allows the melted solder to flow smoothly onto the pads and wires.
- Rosin has the downside of producing smoke that is a lung irritant – avoid inhaling.
- Lead-free wire is available, but requires a higher melting temperature and is more difficult to work with.

## Soldering Technique

- Heat both of the elements that you are
soldering (i.e. the solder pad and the
component wire) for a few seconds, then apply the solder. Solder flows towards heat!
- Don’t keep applying heat to components for more that a few seconds or you may damage them.
- Ensure you have a smooth, shiny, volcano-shaped join and that all the gaps are filled in.
- Watch out for solder bridges/shorts to other pads or components.

## Soldering Technique

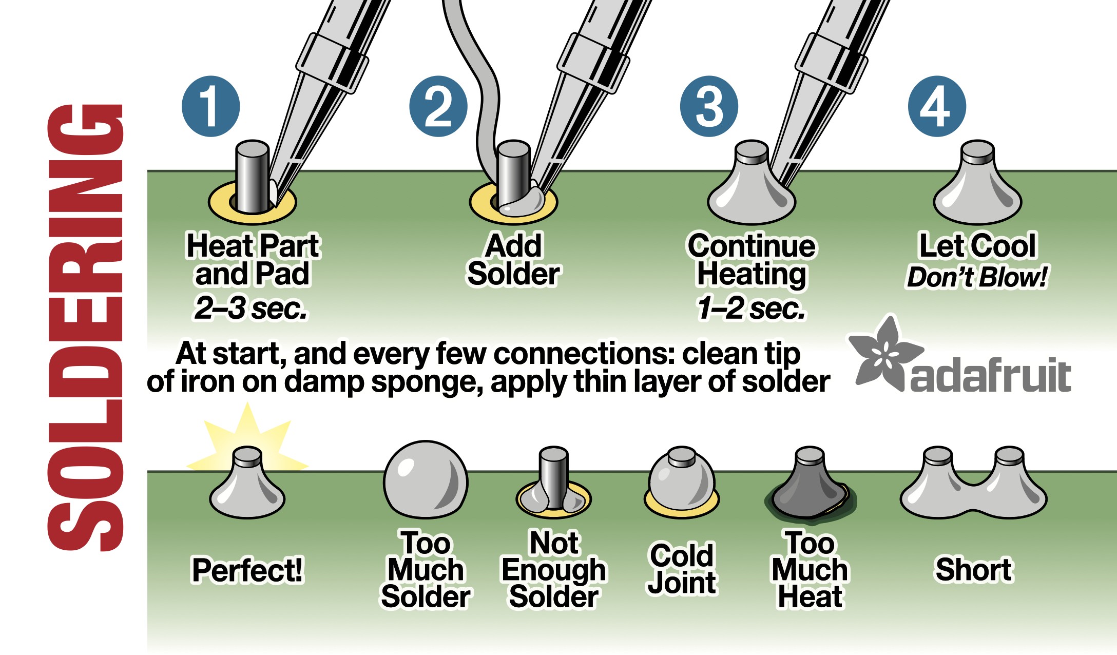
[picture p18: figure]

## Flush Cut Pliers

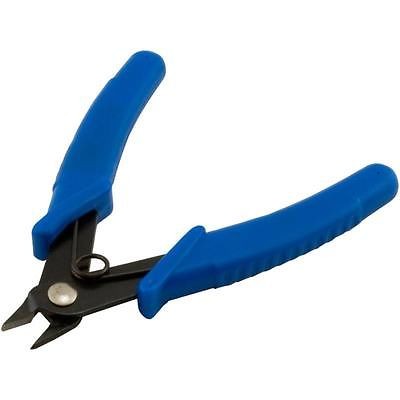
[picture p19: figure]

- Used to trim component lead wires after soldering.
- Good for cutting header pins to length.
- Keep wire cuttings and waste in your plastic cup – not scattered around on your table.

CAUTION!
Leads and pins often separate at high speeds and go flying, so cup them with your hand and don’t point them at your eyes while using.

# Desoldering

Dealing with “Oops!”

## Desoldering Pen (aka Solder Sucker)

Used to suck away solder when removing soldered components.
- Use the plunger to prime the pen, and the button to perform the suction operation.
- Requires a bit of precision and timing as nozzle needs to be pretty close to the liquefied solder and triggered before the solder starts to solidify.
- Often requires multiple attempts to get most of the solder.

## Desoldering Braid/Wick

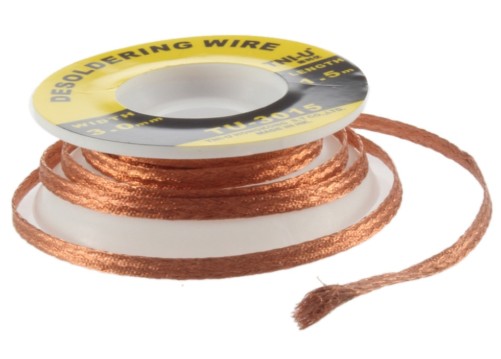
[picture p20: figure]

Used to pull away solder when removing soldered components.
- Use a section of the braid without solder on it.
- Heat the solder through the braid to get the solder to melt and flow onto the braid and then pull it away from the area.
- Solder flows towards heat.

## Desoldering

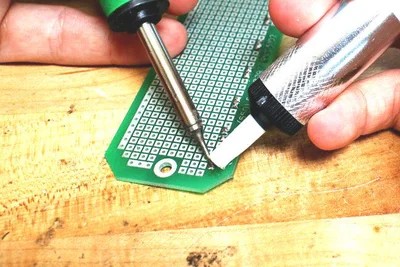
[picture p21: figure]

- Reheat the joint and get as much solder away from it as you can using a desoldering pump
- Alternatively, heat joint through a soldering wick/braid to get the solder to stick to the wick
- Use a pliers to gently pull the component wires from the board
- Reheat and remove any excess solder that is still left
- Insert and solder the replacement component

https://www.instructables.com/id/The-Ultimate-Guide-to-Desoldering/

# Assembling the Board

Putting It All Together

## Safety

- Components and pins can be somewhat sharp so handle carefully.
- If you need to clip or shorten a wire, do it angled downward –
not towards anyone.
- If a component doesn’t fit, reposition and wiggle it instead of forcing it.
- Soldering irons are hot. Only touch the handle.
- Flux contains acid, which is a skin and lung irritant.
Keep away from skin and don’t breathe the fumes.

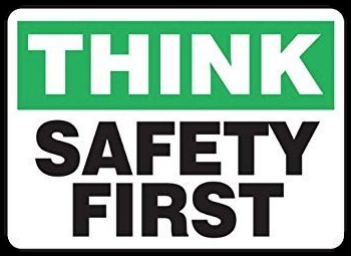
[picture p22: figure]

- Lead is a component of solder wire, so wash hands before eating and avoid rubbing eyes.
- Keep your work area clear, especially of open liquid containers.
- Some components can be damaged by static shock, so grounding
yourself after walking around is generally a good idea
- If you’re not sure if something would be safe or OK, please stop and ask.
- If you see something that looks unsafe, call a stop immediately so it can be evaluated and addressed.

## General Assembly Guidelines

- Keep parts segregated to avoid confusion (especially resistors)
- Start with the smaller/shorter passive components and work towards the larger ones
- Bend resistor leads to a 90 degree angle as close to the body as possible
- If you’re not sure about a resistor’s value, use a multimeter to test it.
- Pay close attention to polarity! (electrolytic capacitors, speaker, battery)
- Even though orientation doesn’t matter for non-polarized components (like resistors) it’s easier to identify them on the board if you orient them consistently.
- Don’t trim leads until after you’ve soldered and inspected them
- Use magnification to check for breaks, shorts, solder bridges, splashes, etc.
- Optional steps for Audio In shown in yellow.

## For a More Pleasant Experience

- Take your time. This isn’t a race. No points awarded for finishing first.
- Check twice, solder once – usually on the back of the board. Desoldering is a bit of a pain.
- Help others around you. No soldier or (solderer) gets left behind.
- Cup up = working on badge
- Cup down = done and good to go
Please put your trimmings/waste in the garbage can first!

Questions?

## Detailed Assembly Instructions: 1

- Start with all the resistors on the board. These will be marked R1 through R15.
- Bend them to 90 angles close to the ceramic body, insert into the board, bend the ends out slightly, and solder on back of board.
- [6] 10K (brown-black-black-red)
- [2] 100K (brown-black-black-orange)
- [2] 220K (red-red-black-orange)
- [2] 1M (brown-black-black-yellow)
- [4] 2M (red-black-black-yellow)
- Inspect and trim leads using flush cut trimmer.

https://circuitdigest.com/calculators/5-band-resistor-color-code-calculator

## Detailed Assembly Instructions: 2

- Place the 4 directional and 4 action buttons (SW2-SW9).
The buttons will only fit with the legs oriented left/right.
- Insert the two thumbwheel pots (RV1, RV2)
- Insert the ceramic capacitors
- 100nF – marked “104” (C1, C2)
- 22pF – marked “22” (C7)
- Solder and inspect the leads.

## Detailed Assembly Instructions: 3

- Snip male pin headers for the PAM8403 amplifier
board (1) 3-pin and (3) 2-pin.
- Put the long end of the pins into the R4ge board and set the amplifier board (U6) on the short ends of the pins.
- Solder the pins to the amplifier board.
- Flip the board over and solder the pins to the R4ge board.
- Inspect and trim the pins. These pins are thicker and can fly at high velocity when trimmed.
Be careful!

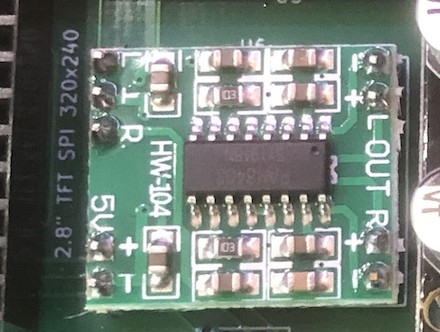
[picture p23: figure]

## Detailed Assembly Instructions: 4

- Snip male pin headers for the PCM5102a I2S DAC board (1) 9-pin and (1) 6-pin.
- Put the long end of the pins into the R4ge board and set the DAC board (U5) on the short ends of the pins.
- Solder the pins to the DAC board.
- Flip the board over and solder the
pins to the R4ge board.
- Inspect and trim the pins.
Again, be careful!

## Detailed Assembly Instructions: 5

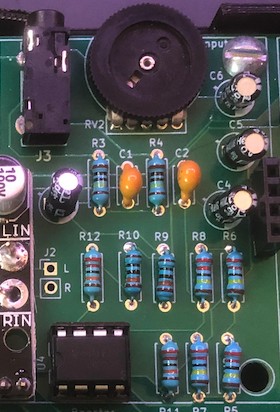
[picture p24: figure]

- Insert the 1/8” TRS audio jack (J3)
- Insert the 10uF electrolytic capacitors (C3 – C6).
- The white half of the footprint indicates the NEGATIVE lead.
- The white stripe on the capacitor is negative.
- Insert the 8-pin IC socket for the TL072 (U4)
with the notch to the left.

## Detailed Assembly Instructions: 6

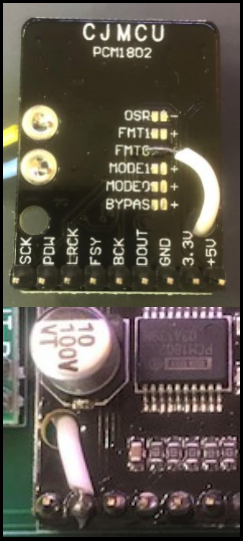
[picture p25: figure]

- Snip a 1” wire and strip about 1/8” from one end.
- Solder it to the FMT0 solder bridge on the back of
the PCM1802 ADC board (U3) so that both pads are connected.
- Run the other end through the hole on the ADC.
- Strip the wire to the length shown.

## Detailed Assembly Instructions: 7

- Snip a 9-pin male header for the PCM1802a I2S ADC board, and (2) 1-pin headers for LIN and RIN.
- Put the long end of the pins into the R4ge board
and set the ADC board (U5) on the short ends of
the pins.
- Solder the pins to the DAC board.
- Solder the wire to the 3v3 pin (2nd from left)
- Flip the board over and solder the
pins to the R4ge board, ensuring no gap between the ADC and R4ge PCBs under the 3 capacitors. ADC board will NOT be fully parallel to PCB.

## Detailed Assembly Instructions: 8

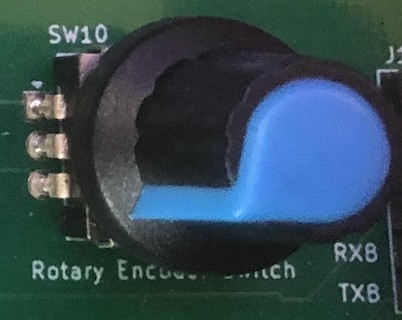
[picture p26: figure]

- Insert the rotary encoder
(SW10)
- Insert the joystick (U7)
- This has a lot of pins, so may take some finesse to get them all seated.
- A pen or small screwdriver can be helpful to push the pins.
- Insert the power switch (SW1)
- Flip over, solder, and inspect.

## Detailed Assembly Instructions: 9

- Cut (4) 1” sections of wire for the speakers.
- Strip 1/8” from one end.
- Strip all but 1/4” from the rest.
- Solder the 1/8” ends to the pads on the back of the speakers.
- Attach the (4) M2 standoffs to the holes by the speakers using M2 screws from the back of the board.
- Don’t over-tighten.

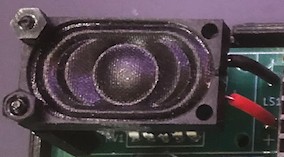
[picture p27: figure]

## Detailed Assembly Instructions: 10

- GENTLY bend the speaker wires to 90 degrees.
- Insert the free end of the speaker wires into the PCB.
- Ensure that the holes on the speaker fit over the standoff threads and the speaker is parallel to the PCB (or angled slightly inward)
- May need to strip off a bit more insulation if too long.
- Attach speakers to standoffs using the small M3 nuts.
- Solder the speaker wires to the back of the board.

## Intermission

If you haven’t already done so,
take a short brain and bio break at this point.

## Detailed Assembly Instructions: 11

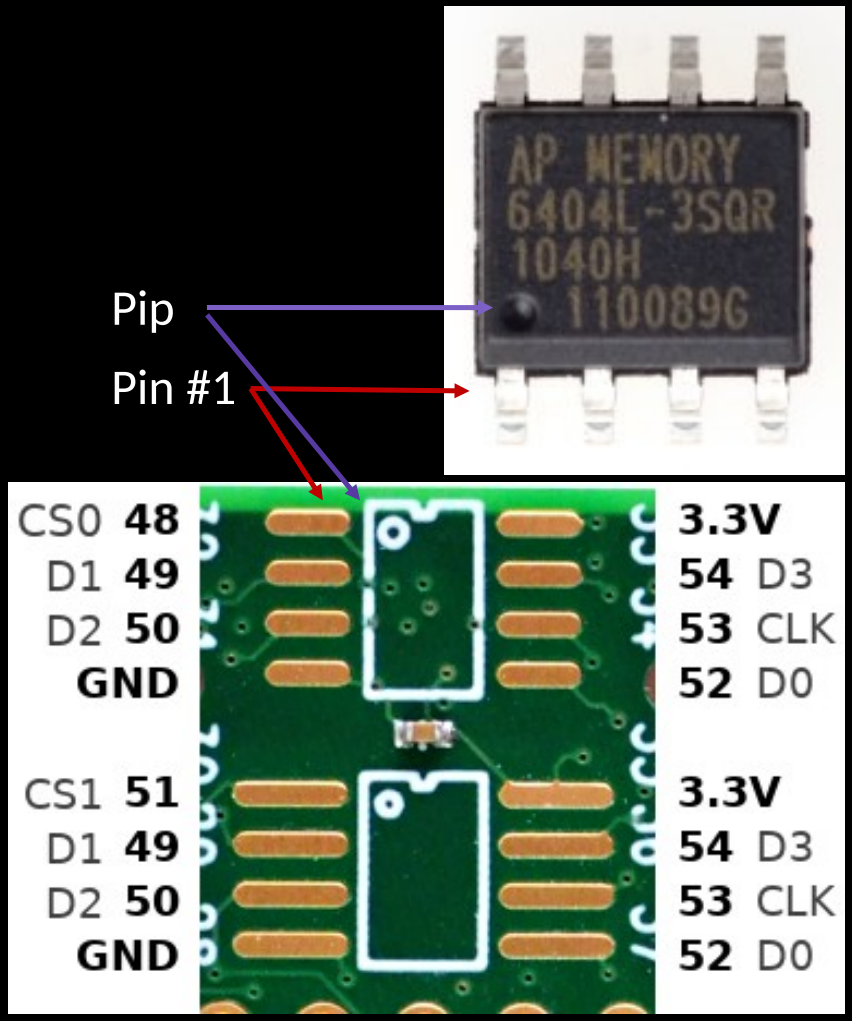
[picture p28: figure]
Pip; Pin #1

- Flip the Teensy 4.1 over and locate the pads for
the PSRAM memory chip.
- Place a small dab of solder on pad 48.
- Take the QSPI memory chip and
place it on the footprint closest
to the end of the board (pads 48 –
52) aligning the pip on the chip with the circle on the footprint.
- Holding the chip down with a
tweezers or pencil, keep it aligned with the other pads as you melt the corner solder.
- Solder the other 7 leads to the pads.
- Inspect closely!

## Detailed Assembly Instructions: 12

- Optional: take a 5-pin male angled header and
solder to Teensy as shown. This is allows the
Teensy to act as a USB host device (keyboard, MIDI)
- Optional: take a 6-pin male angled header (J1) and attach to R4ge PCB as shown. This allows you to attach I2C and UART peripherals. Also helpful for attaching power and ground clips for continuity testing/troubleshooting.

## Detailed Assembly Instructions: 13

- Snip (2) each 24-pin male and female pin headers to fit the Teensy.
- Put the female headers in the R4ge PCB.
- Place the long ends of the male headers into the female headers.
- Place the Teensy over the short ends of the male headers and push down gently until all pins are seated flush.
- Solder the male pins to the Teensy. Flip over and solder to R4ge PCB.

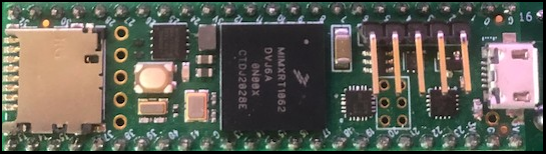
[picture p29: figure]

## Detailed Assembly Instructions: 14

- Snip (1) each 4-pin male and female pin headers to fit the TFT display, and (1) 14-pin female header.
- Put the female headers in the R4ge PCB.
- Place the long ends of the male headers into the female headers.
- Place the TFT over the
short ends of the male
headers and push down
gently until all pins are
seated flush.
- Solder the male pins to the TFT. Flip over and solder
to R4ge PCB.

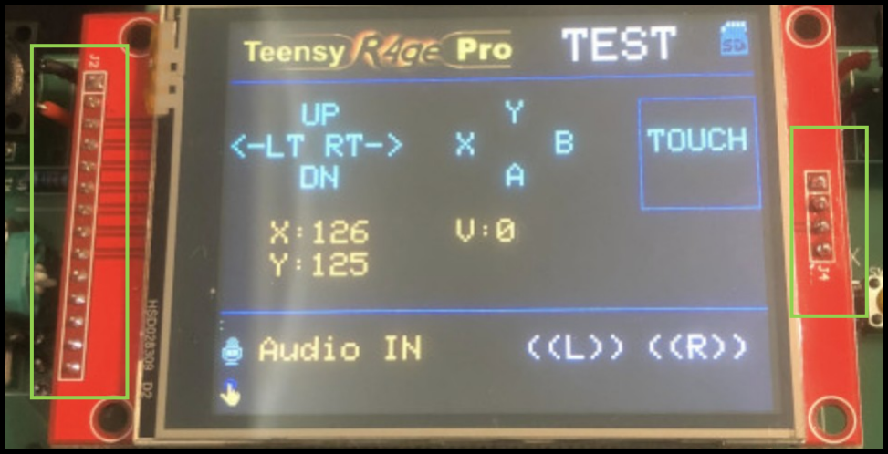
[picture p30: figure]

## Initial Test

1. Hook up the Teensy to your laptop using the Micro USB cable.
2. The test app should boot up. If not, disconnect cable and see the Troubleshooting slides in the Testing section.
3. SD icon should be shown in upper right corner with a red line through it.
4. Press all the buttons, move the joystick, and rotate the encoder. Verify that the corresponding element value is displayed or highlighted on the screen.
5. In addition, the following buttons have additional actions that should be triggered:
- Left: audio from left speaker
- Right: audio from right speaker
- Up: Sample audio in (green bars indicate left and right channel signal strength)
- Down: stop sampling audio in
6. You may need to adjust the volume (under the left speaker) to get audio output. Clockwise = Louder

## Detailed Assembly Instructions: 15

- Snip (6) 1-pin male and female pin headers for the TP4056 charger.
- Flip the R4ge board over and place the long ends of the pins into the R4ge PCB and place the charger on the short end of the pins.
- Solder the pins to the charger.
- Flip over to the front of the R4ge board and solder the pins there.
- Inspect and trim the pins.

## Detailed Assembly Instructions: 16

- Insert the battery holder on the back of the board.
- Pay attention to the polarity (negative to the left)
- Flip over and solder on the front. Don’t be stingy here!

CONGRATULATIONS – ASSEMBLY IS COMPLETE!!!

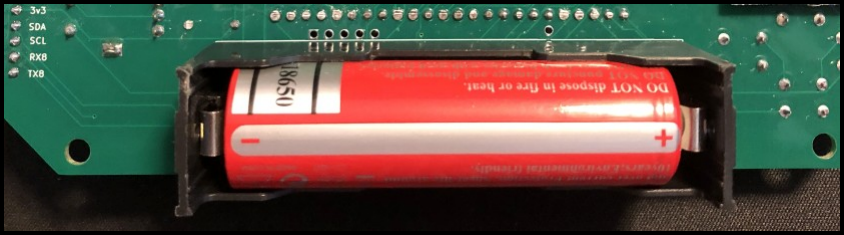
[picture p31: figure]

Time for the final test…

# Testing

Keep Your Fingers Crossed

## Testing the Assembled Board

1. Insert the SD card.
2. Hook up the Teensy to your laptop using the Micro USB cable.
3. The test app should boot up.
4. SD icon should be shown in upper right corner.
5. Press all the buttons, move the joystick, and rotate the encoder. Verify that the corresponding element value is displayed or highlighted on the screen.
6. In addition, the following buttons have additional actions that should be triggered:
- Left: audio from left speaker
- Right: audio from right speaker
- Up: Sample audio in (green bars indicate left and right channel signal strength)
- Down: stop sampling audio in
7. You may need to adjust the volume (under the left speaker) to get audio output. Clockwise = Louder

## Testing Battery Operation

1. Disconnect the USB cord from the Teensy.
2. Ensure the power switch is in the “CHG” position (all the way to the bottom)
3. Place the loop of ribbon across the battery holder perpendicularly. (Not required if you have exceptionally strong fingers or enjoy the challenge of battery extraction.)
4. Take a CR18650 battery and insert it with the positive end pointed towards the right side of the board and firmly seat in place.
5. Attach the USB cable to the battery charger.
6. Lights on the charger should be red, indicate the battery is charging.
7. Move the switch up to the USB position. Test app should boot up.
8. Repeat the previous button test.
9. Move switch back to CHG position to allow battery to fully charge (charger light will turn blue when done)

## Troubleshooting – Dead Board

If you get no response from the board at all:
- Remove the Teensy from the board and see if the power light comes on when hooked up to your laptop via the USB cable
- Ensure you have the Teensy oriented on the board correctly with the USB port to the right
- Swap your Teensy with a different one
- Swap out your TFT display
- Swap out your USB cable
- Connect the USB to a 5v 1A transformer (i.e. iPhone charger) instead of your laptop

Change only 1 element/test parameter at a time. DON’T THRASH!

## Troubleshooting Components

If the board works, but one or more particular subsystems or components are non-functional:
- Re-examine the solder joints, looking for shorts/solder bridges (preferably under magnification)
- Scrub the back of the board lightly with a brush to remove any fine solder splashes/shorts.
- Ensure you have the polarity/orientation correct (battery, electrolytic capacitors, ICs)
- Re-heat/re-flow the solder for the non-functional component.
- Verify the component using a multimeter, logic probe, or oscilloscope.
- Look for discolorations or deformities that indicate a capacitor or trace is burned out.
- Swap out the component with a verified operational one.
Use the schematic to help identify the components that may be involved in the failure!

## Finishing Touches

- Ensure you’ve put your name on the board somewhere
(they all look alike)
- Take a picture of your completed board for posterity #codemash2022
- Prepare for the afternoon session:
- Ensure VS Code withPlatformIO and Arduino IDE
is installed on you laptop
- Check that your laptop recognizes the Teensy when connected via USB
- Full prerequisite instructions:
https://prereqs.codemash.org/ (https://prereqs.codemash.org/Files/Portable_Gaming_System_PreReqs.pdf)
- Download at least one Doom1 WAD to your laptop

https://www.wad-archive.com/wad/Doom-Shareware-v1.9 Keep cups for PM session

## Acronyms and Abbreviations

- ADC: Analog to Digital Conversion
- DAC: Digital to Analog Conversion
- DMA: Direct Memory Access
- GND: Ground
- GPIO: General Purpose Input Output (pins)
- I2C: Inter-Integrated Circuit pronounced "I squared C" (serial bus with 2 pins: SCL, SDA)
- I2S: Inter-IC Sound (serial audio protocol with 3 or 4 pins: SCK/BCLK, WS/LRCLK, SD/SDATA, MCLK optional)
- MCU: Micro Control Unit
- MISO: Master In - Slave Out (SPI pin) sometimes referred to as SDI on a master
- MOSI: Master Out - Slave In (SPI pin) sometimes referred to as SDO on a master
- PCM: Pulse Coded Modulation (WAV files)
- PWM: Pulse Width Modulation
- RXD: Receive Data (UART pin)
- SCK: Serial Clock (SPI pin)
- SCL: Serial Clock (I2C pin)
- SDA: Serial Data (I2C pin)
- SPI: Serial Peripheral Interface (4 pins: SCK, MOSI, MISO, SS)
- SRAM: Static Random Access Memory
- SS: Slave Select (SPI pin) Also known as CS (Chip Select)
- TFT: Thin Film Transistor (Liquid Crystal Display)
- TTL: Transistor Transistor Logic (0v/LOW & Vcc/HIGH)
- TXD: Transmit Data (UART pin)
- UART: Universal Asynchronous Receiver/Transmitter (2 pin interface using RXD and TXD pins)
- USB: Universal Serial Bus
- V+ / Vbus / Vcc - Voltage positive signal (USB header pin)
- VREF: ADC reference voltage, usually 1/2 the ADC voltage range, i.e. 1.65v for 3.3v logic

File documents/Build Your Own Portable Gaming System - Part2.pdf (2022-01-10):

# Build Your Own Portable Gaming System

Paul Pagel

### Build Your Own Portable Gaming System

If you have not already done so:

Download the pre-requisites instructions and complete all downloads and installations
http://prereqs.codemash.org/

Download at least one Doom1 WAD to your laptop https://www.wad-archive.com/wad/Doom-Shareware-v1.9

Slide deck download (PDF): https://github.com/DigiTorus86/Teensy-R4ge-Pro/tree/master/documents

## Session Objectives

Load and run different emulators and games on the hardware.

Learn how to use the Teensy Audio Library and hardware peripherals in custom games and other programs.

Troubleshoot and resolve any lingering hardware issues.

## Pre-Requisites

- Working Teensy R4ge Pro with 8MB PSRAM installed
- VS Code with Platformio and Teensy platform
- Arduino IDE with Teensyduino
- Micro SD card formatted for FAT32
- Clone of https://github.com/Jean-MarcHarvengt/MCUME/
- Clone of https://github.com/DigiTorus86/Teensy-R4ge-Pro/

# IDE Setup and Verification

Are you ready?

## Arduino IDE

1. Ensure Teensy is connected to your laptop via USB
2. Launch the Arduino IDE
3. Open the teensy-r4ge-pro-test sketch
4. Under Tools → Board, select “Teensy4.1”
5. CPU Speed: “600 MHZ”

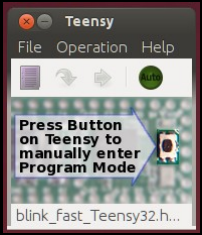
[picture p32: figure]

6. Select the Port that the Teensy is on (this will vary by system and OS)
7. Programmer: “AVR ISP” or “AVR ISP mkII”
8. Go to Sketch → Upload (or click the right arrow button)
9. Should compile and the Teensyduino app should launch

## Verification

- Ensure that all peripherals are still working as expected. Use the instructions in the header comments if needed.
- Change line 155 to some other (family-friendly) short word.
- Re-upload and verify that the title text changed accordingly.
- The test app is a good resource for
simple example code to use the
hardware and peripherals.


# Doom

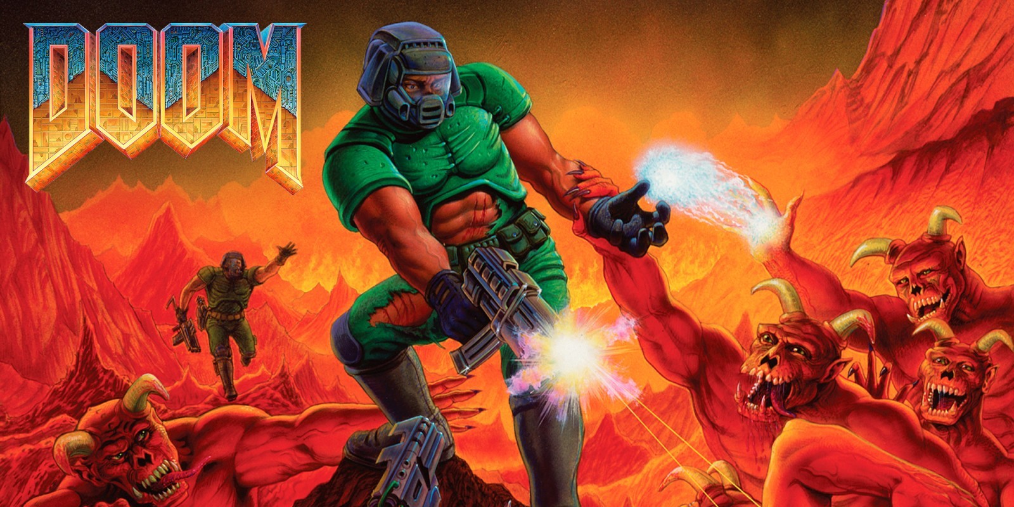
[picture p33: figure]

What to do when all hell breaks loose

## A Brief History

- Originally released in December 1993
- Source code released in 1997
- Many sequels and spin-offs

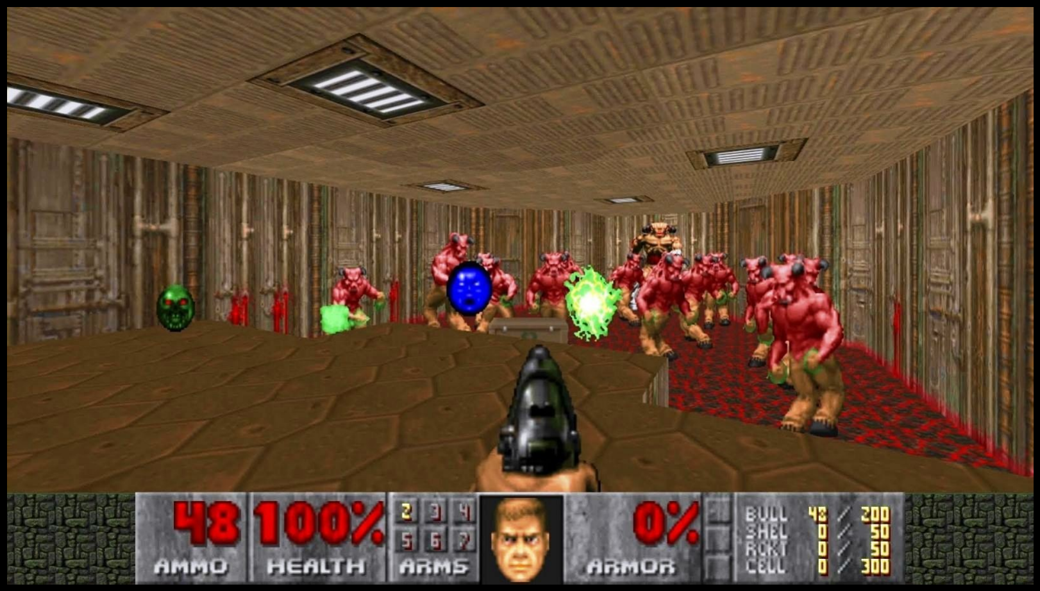
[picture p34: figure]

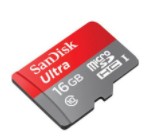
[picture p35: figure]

## Prepare the SD Card

1. Create a local folder named “MCUME-SD”
2. Extract the sd.zip file from the MCUME repo to it.
3. Copy the DOOM1.WAD file to the data folder.
4. Copy the contents of MCUME-SD to the micro SD card root. (The data folder should be at the SD root.)
5. Insert the SD card into the Teensy.

## Source and Settings

1. In the ArduinoIDE, open the Teensy-R4ge-Pro/MCUME/teensydoom/ folder. 2.Under Tools → Optimize, select “Faster” 3.Upload the sketch to the Teensy.

## Doom Modifications – iopins.h

#define TFT_CS | 10

#define TFT_RST | 255

#define PIN_JOY2_A1X 16

#define PIN_JOY2_A2Y 17

#define PIN_JOY2_BTN 25

#define PIN_KEY_USER1 2 // BTN A #define PIN_KEY_USER2 3 // BTA B #define PIN_KEY_USER3 4 // BTN X #define PIN_KEY_USER4 5 // BTN Y

// Second joystick
#define PIN_JOY1_BTN 24 // Encoder button

#define PIN_JOY1_1 | 29 // UP

#define PIN_JOY1_2 | 30 // DOWN

#define PIN_JOY1_3 | 32 // RIGHT

#define PIN_JOY1_4 | 31 // LEFT


## Doom Modifications - platform

platform_config.h changes:

#define INVX | 1

#define INVY | 1

#define ILI9341 | 1

## Running the Emulator

- Use the Up/Down buttons or joystick to change selection.
- Press rotary encoder button to select file.
- Press Y button to reset emulator.

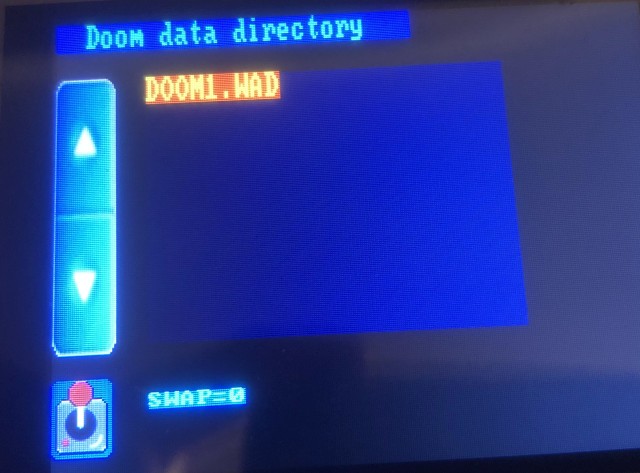
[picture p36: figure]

If screen is blank, re-insert SD card and reboot hardware.

## Playing DoomTM

- Change menu selection: Up/Down buttons or joystick
- Select menu, get item: A button
- Fire: Rotary encoder button
- Door/switch: B button
- Show Map: X button

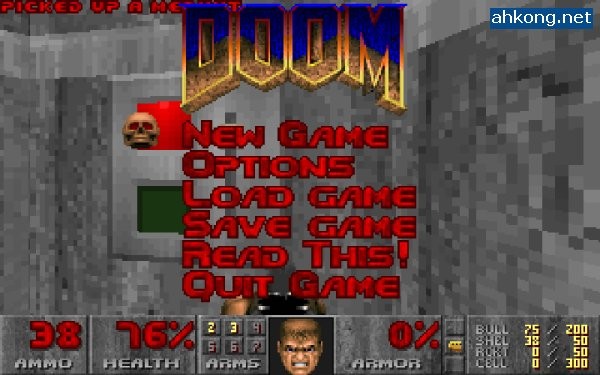
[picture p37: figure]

Unfortunately, no sound available.

# Other Emulators

Running old systems on new hardware

## General Instructions

- Obtain emulator game files.
- Copy game files to corresponding emulator folder on SD card.
- Copy the iopins.h and platform_config.h files from the Digitorus86/Teensy-R4ge-Pro/MCUME folder to the MCUME/MCUME_teensy41/ folder.
- Load the emulator into ArduinoIDE.
- Select the appropriate Tools->Optimize setting.
- Upload to the Teensy.

## Castaway – Atari ST

1. Save .st game files to “st” folder on SD card.
2. Copy the iopins.h and platform_config.h files from the Teensy-R4ge-Pro/MCUME/teensycastaway41/ to the MCUME/MCUME_teensy41/teensycastaway41/ folder.
3. Load into ArduinoIDE and select “Smallest Code” option.

## Castaway – Verified Games

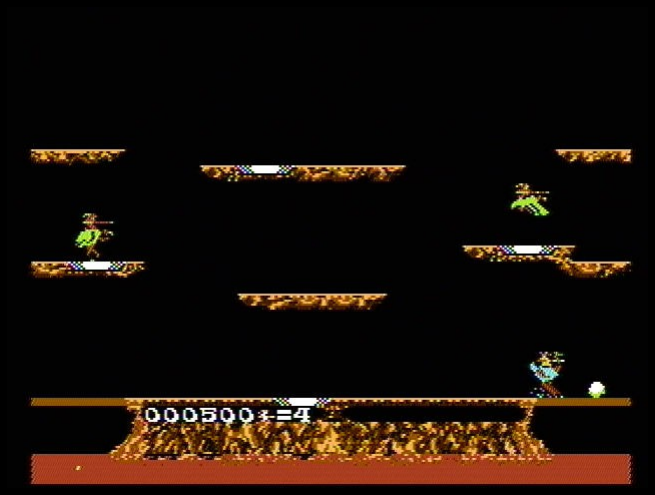
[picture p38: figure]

- 1943 (with sound)
- 23 Games
- Battlezone

●

Joust
- Arkanoid
- Caves of Rigel
- Crossbow
- Defender of the Crown
- Dragon Spirit
- Flying Shark
- Fusion

●

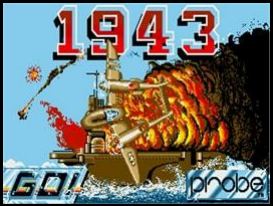
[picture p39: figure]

Ivanhoe
- Karate King
- Slightly Magic
- Super Sprint
- Twin World

## Ultimate Amiga Emulator

1. Save .ADF or .HDF files to “amiga” folder on SD card.
2. Copy the iopins.h and platform_config.h files from the Teensy-R4ge-Pro/MCUME/teensyuae41/ to the MCUME/MCUME_teensy41/teensyuae41/ folder.
3. Load into ArduinoIDE and select “Smallest Code” option.

## Nofrendo – NES

1. Save files to “nes” folder on SD card.
2. Copy the iopins.h and platform_config.h files from the Teensy-R4ge-Pro/MCUME/teensynofrendo/ to the MCUME/MCUME_teensy/teensynofrendo/ folder.
3. Load into ArduinoIDE and select “Faster” option.

## Nofrendo – Verified Games

- Super Mario Brothers
- Tetris
- Donkey Kong
- Donkey Kong Jr.
- Elevator Action
- Galaga
- Faxanadu
- Ms. Pac Man
- Q*Bert
- Xevious

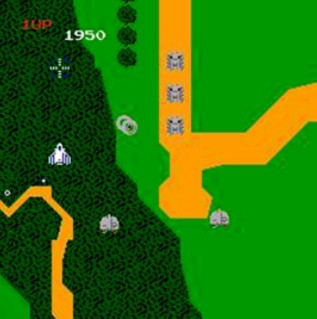
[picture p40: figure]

## USB Keyboard

Teensy can act as a USB host for peripherals, such as a keyboard. Some games (especially for computer emulators) will require a keyboard.
To use:
- Attach host cable to Teensy with black wire to left, red to right.
- Attach USB device to host cable.

## UAE – Verified Games

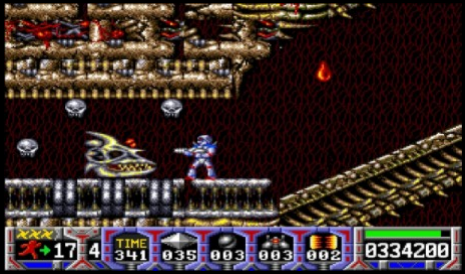
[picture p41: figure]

- Battle Squadron
- Elite
- SturmTruppen
- Turrican
- Turrican 3

# Custom Sketches

Creative DIY Hackery

## VS Code + PlatformIO

If you plan to do any custom development, VS Code + PlatformIO is STRONGLY recommended!
- Modern IDE
- Much better developer experience
- Excellent industry support

## VS Code + PlatformIO

1. Launch VS Code.
2. File → Open folder:
Teensy-R4ge-Pro/PlatformIO/teensy-r4ge-pro-test
3. Make sure the Teensy is connected to your laptop.
4. Click the upload button in the
bottom toolbar.

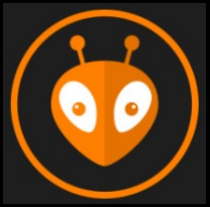
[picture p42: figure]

## Teensy Audio

Teensy 4.1 is capable of sophisticated, high-quality audio generation, capture, and processing.

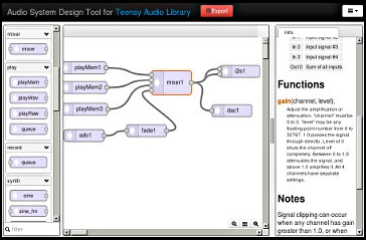
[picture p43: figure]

Online Audio Design GUI
https://www.pjrc.com/teensy/gui/

Imports and exports C code

## Teensy Audio Network

Basic Structure:
Source(s) → Effects/Filters/Mixers → Output
Synthesizers | | Chorus/Reverb
WAV files | → | Low Pass | → I2S DAC (Inter IC Sound)
I2S ADC | | Channel Mix

## Teensy Audio - Import

1) Launch Teensy Audio GUI in browser: https://www.pjrc.com/teensy/gui/?info=AudioMixer4
2) Copy the code between the //GUItool comments in test sketch
3) Click IMPORT on the Audio GUI and paste into the textbox

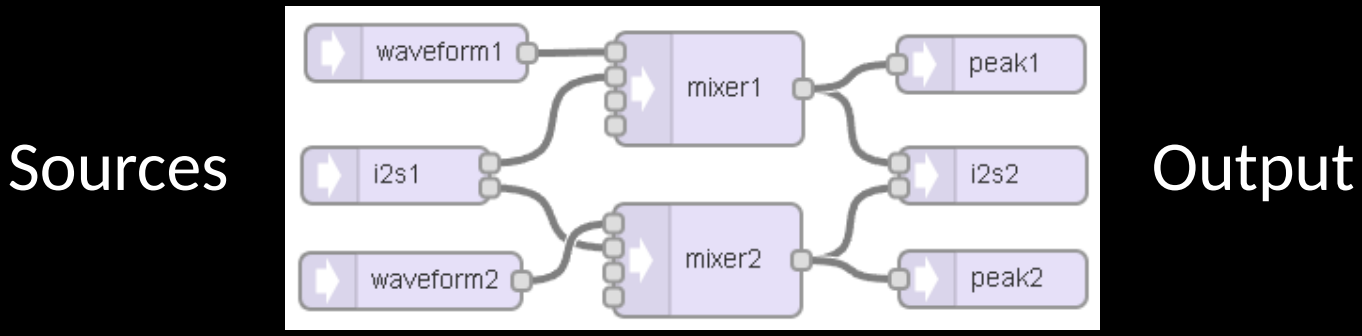
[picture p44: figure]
Sources; Output

## Teensy Audio - Export

1) Modify the signal chain as shown:
2) Export to clipboard and paste back
into sketch.

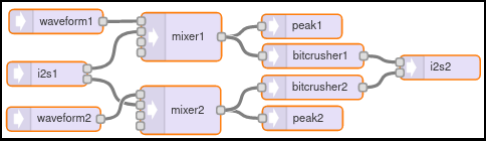
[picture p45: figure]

3) Add the following at line 185 in the sketch:
bitcrusher1.bits(4);
bitcrusher2.bits(8);
4) Upload the sketch and hear the difference by pressing the left and right buttons.
5) Experiment with other bit values and/or filters.

// GUItool: begin automatically generated code
AudioInputI2S | i2s1; | //xy=668.75,348
AudioSynthWaveform | waveform2; | //xy=676.75,404
AudioSynthWaveform | waveform1; | //xy=679.75,283
AudioMixer4 | mixer2; | //xy=834.75,393
AudioMixer4 | mixer1; | //xy=835.75,302
AudioAnalyzePeak | peak1; | //xy=985.75,289
AudioAnalyzePeak | peak2; | //xy=986.75,403
AudioEffectBitcrusher | bitcrusher2; | //xy=998.75,364.75
AudioEffectBitcrusher | bitcrusher1; | //xy=999.75,325.75
AudioOutputI2S | i2s2; | //xy=1157.75,340
AudioConnection | patchCord1(i2s1, 0, mixer1, 1);
AudioConnection | patchCord2(i2s1, 1, mixer2, 1);
AudioConnection | patchCord3(waveform2, 0, mixer2, 0);
AudioConnection | patchCord4(waveform1, 0, mixer1, 0);
AudioConnection | patchCord5(mixer2, peak2);
AudioConnection | patchCord6(mixer2, bitcrusher2);
AudioConnection | patchCord7(mixer1, peak1);
AudioConnection | patchCord8(mixer1, bitcrusher1);
AudioConnection | patchCord9(bitcrusher2, 0, i2s2, 1);
AudioConnection | patchCord10(bitcrusher1, 0, i2s2, 0);
// GUItool: end automatically generated code

## Teensy Graphics

- Use the Teensy-specific (xxx_t3) graphic libraries for most applications.
- Use the direct memory access (DMA) libraries for situations where fastest performance is required. https://github.com/KurtE/ILI9341_t3n
- Graphics performance limited by speed of SPI bus between Teensy and the display.

## Teensy Graphics – Demo

- Load the sketch:
Teensy-R4ge-Pro/PlatformIO/teensy-r4ge-pro-shooter-demo
- Demonstrates full screen scrolling, transparent drawing, and simple rotational movement.

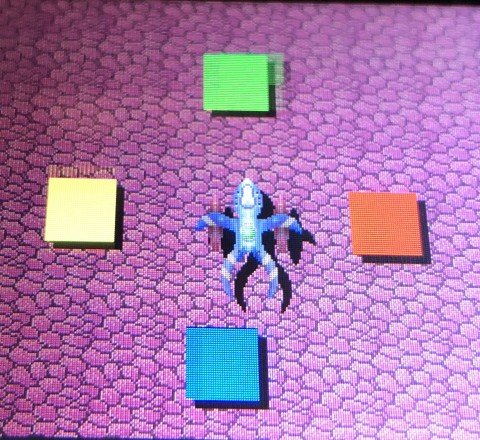
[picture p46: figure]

## Tombstone City

- Teensy-R4ge-Pro/PlatformIO/teensy-r4ge-tombstone
- An emulation of the classic TI-99/4A game
by John Plaster for Texas Instruments
- Tile-based graphics

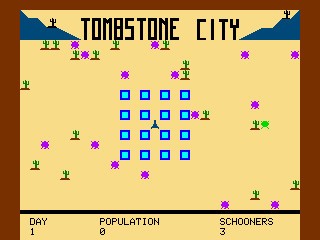
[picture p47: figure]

## Gravitack

- Teensy-R4ge-Pro/PlatformIO/teensy-r4ge-gravitack
- Vector-based homage to the
arcade console game


# Ideas and Next Steps

Where do you go from here?

## Topics

- More emulators
- Sensors and other peripherals
- Common Protocols (I2C, SPI, I2S, UART, CAN bus)
- Motor and servo control
- VGA Output
- Making your own PCBs
- Surface mount soldering

## Project-Driven Discovery

Find something you want to do (real-world application) ...something that excites you
...something that you can accomplish in less than 1 month ...and figure out how to do it!

## CodeMash Contest

Categories
- Audio Alchemy
- Maker Magic
- Technical Wizardry


Bring submissions to the Maker Space before noon on Friday for consideration. CodeMash staff will take a short video, along with your name and email. Must be present Friday afternoon to win.

## Questions?


## Resources

- Adafruit GFX Library
https://learn.adafruit.com/adafruit-gfx-graphics-library/overview
- PJRC Forum
https://forum.pjrc.com/
- Amp Hour Podcast / EEV Blog


Contact Info for Paul Pagel pjpagel86@gmail.com

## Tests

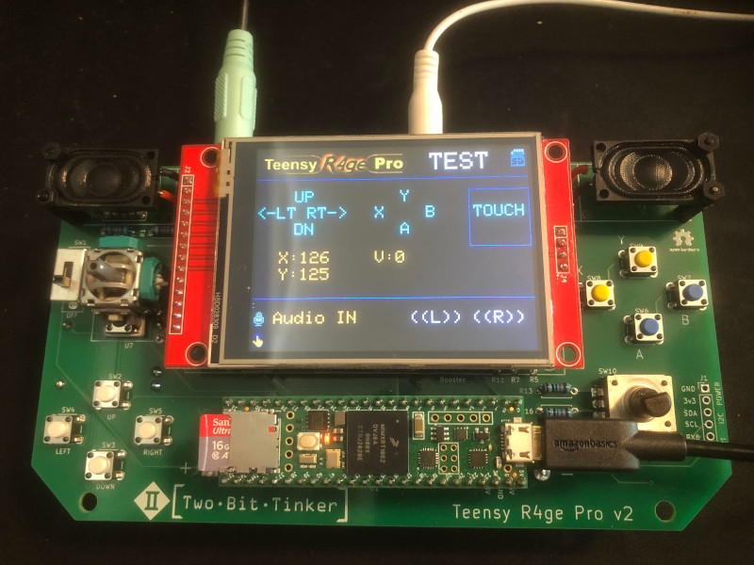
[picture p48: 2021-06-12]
images/teensy-r4ge-pro-test.jpg

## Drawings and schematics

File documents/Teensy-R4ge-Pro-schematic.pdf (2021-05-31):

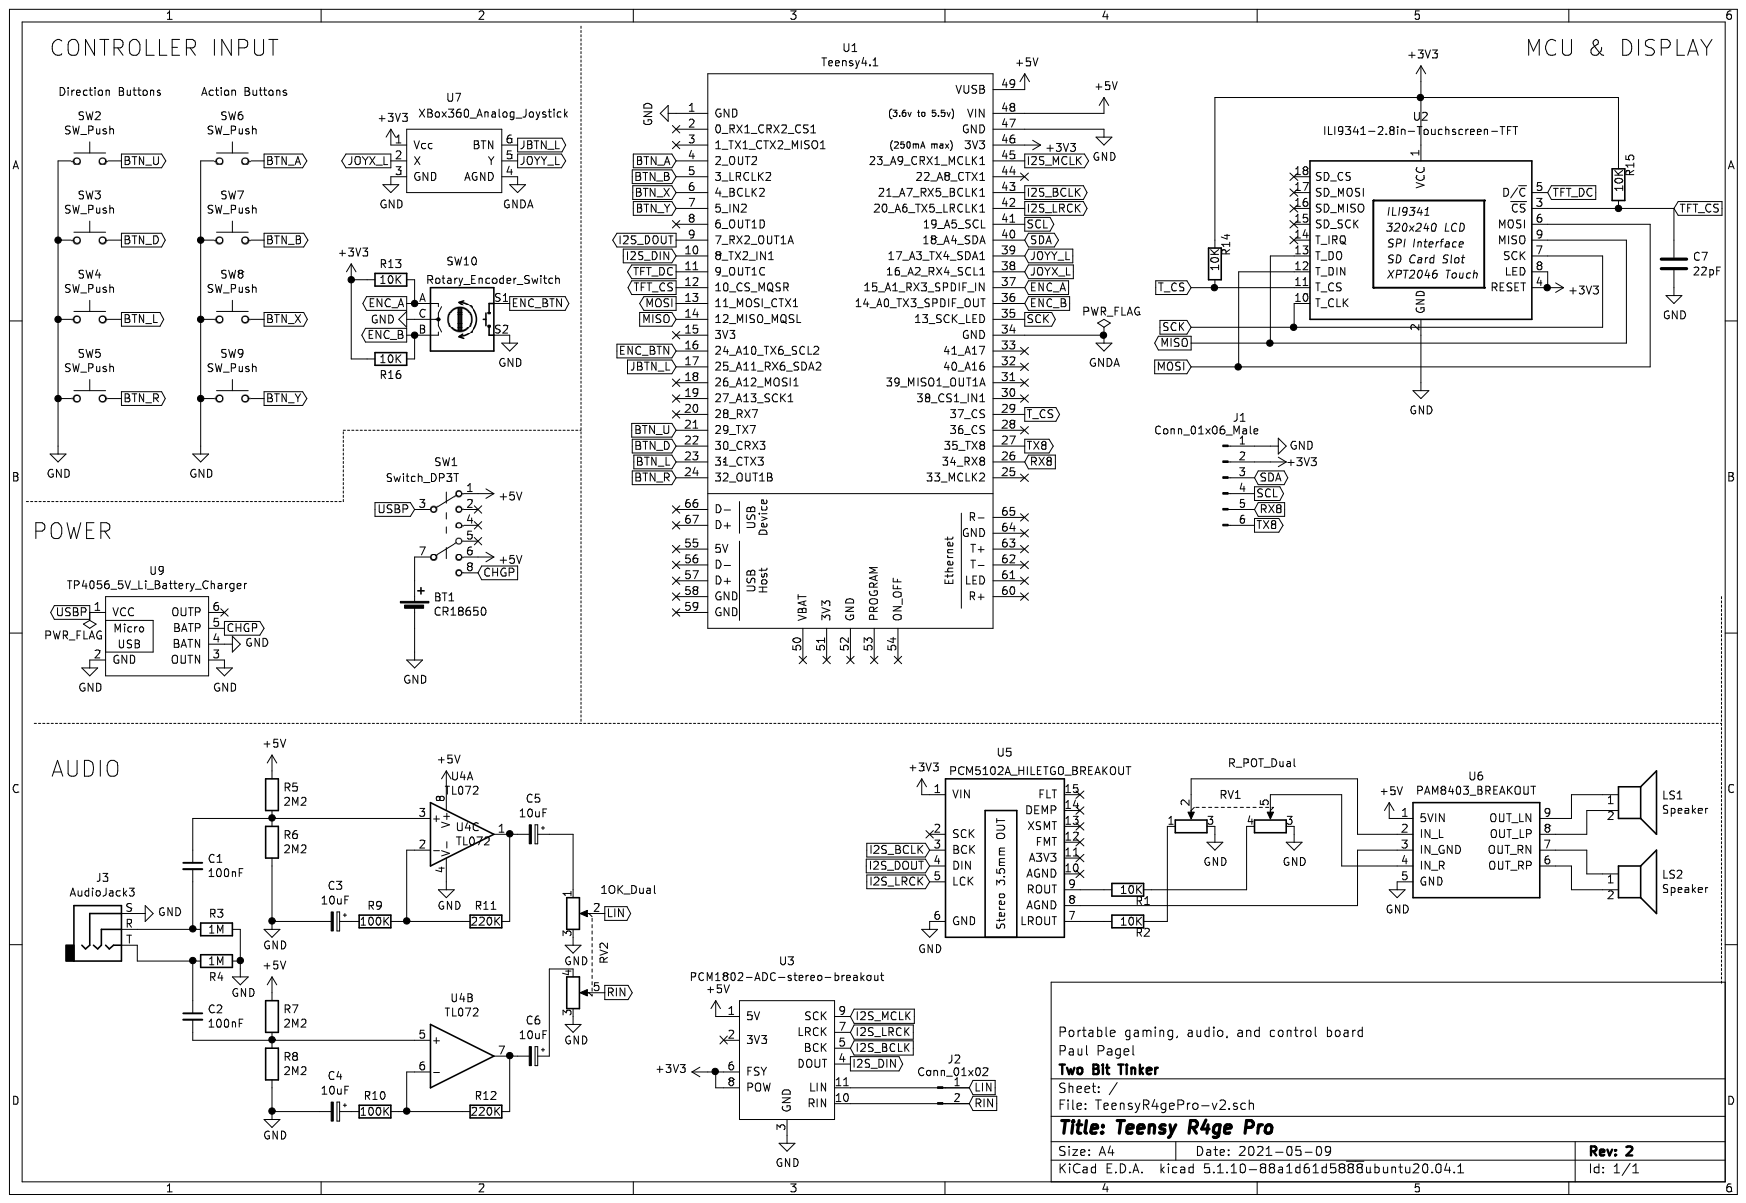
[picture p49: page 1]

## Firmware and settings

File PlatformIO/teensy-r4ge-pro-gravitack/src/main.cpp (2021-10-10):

/***************************************************
Gravitack
An homage to the classic arcade console

Requires:
 - Teensy R4ge Pro v2
 - Teensy 4.1 board

Copyright (c) 2021 Paul Pagel
This is free software; see the license.txt file for more information.
There is no warranty; not even for merchantability or fitness for a particular purpose.
*****************************************************/

#include "SD.h"
#include <SPI.h>
#include <ILI9341_t3n.h>
#include <Audio.h>
#include "teensy_r4ge_pro.h"

#include "Levels.h"
#include "Bitmaps.h"
#include "fire_wav.h"
#include "refuel_wav.h"
#include "explosion_wav.h"
#include "warp_wav.h"
#include "tick_wav.h"

#define SHIP_SIZE    8
#define THRUST_SIZE  3 
#define SHOT_SPEED   8
#define MAX_SHOTS    4
#define MAX_GROUND  32
#define MAX_FUEL     8
#define MAX_TURRET   8
#define MAX_LIVES    6

#define PLAYER_FUEL_X 30
#define GAME_TOP   20 
#define FUEL_WD     8
#define FUEL_HT    16
#define INVALID_ITEM 999

enum game_state_type {
  STATE_TITLE,
  STATE_RULES,
  STATE_PLAYING,
  STATE_PAUSED,
  STATE_GAME_OVER
};

enum direction_type {
  DIR_UP = 1,
  DIR_DOWN = 2,
  DIR_LEFT = 3,
  DIR_RIGHT = 4
};

enum game_state_type game_state;

// constants used to speed up trig calculations
const double PId2  = PI / 2;
const double PId15 = PI / 1.5;
const double PIx15 = PI * 1.5;
const double PIx075 = PI * 0.75;

bool btnA_pressed, btnB_pressed, btnX_pressed, btnY_pressed;
bool btnUp_pressed, btnDown_pressed, btnLeft_pressed, btnRight_pressed;
bool btnA_was_pressed, btnB_was_pressed, btnX_was_pressed, btnY_was_pressed;
bool btnUp_was_pressed, btnDown_was_pressed, btnLeft_was_pressed, btnRight_was_pressed;
bool btnA_released, btnB_released, btnX_released, btnY_released;
bool btnUp_released, btnDown_released, btnLeft_released, btnRight_released;
bool joy_pressed, knob_pressed;

int16_t joy_x_left, joy_y_left, joy_x_right, joy_y_right; 
int16_t joy_x, joy_y; 

static int    player_start_x, player_start_y;
static double player_ctr_x = SCREEN_WD / 2;
static double player_ctr_y = SCREEN_HT / 4;
static double player_rotation = PIx15;
static double player_speed_x;
static double player_speed_y;
static double player_fuel;
static int    player_lives;
static long   player_score;
static long   next_ship = 10000;
static double gravity = 0.02;
static int    level;
static int    level_delay = 10;

int ship_x[9];
int ship_y[9];
int shot_x[MAX_SHOTS];
int shot_y[MAX_SHOTS];
int shot_range[MAX_SHOTS];
double shot_speed_x[MAX_SHOTS];
double shot_speed_y[MAX_SHOTS];
int player_shot_range; // # of game loops new shots can exist

int ground_x[MAX_GROUND];
int ground_y[MAX_GROUND];
int ground_size = 0;  // # of ground line segments in the current level

int  fuel_x[MAX_FUEL];
int  fuel_y[MAX_FUEL];
bool fuel_active[MAX_FUEL];
int  fuel_count;    // # starting fuel packs in level
int  fuel_remaining;  // # remaining fuel packs in level

int  turret_x[MAX_TURRET];
int  turret_y[MAX_TURRET];
int  turret_dir[MAX_TURRET];
bool turret_active[MAX_TURRET];
int  turret_shot_x[MAX_TURRET];
int  turret_shot_y[MAX_TURRET];
int  turret_shot_range[MAX_TURRET];
double turret_shot_speed_x[MAX_TURRET];
double turret_shot_speed_y[MAX_TURRET];
int  turret_range;    // # of game loops new turret shots can exist
int  turret_count;    // # starting turrets in level
int  turret_remaining;  // # remaining turrets in level

int turret_offset_x[4] = { 10, 10,-10, 20};
int turret_offset_y[4] = {-10, 10, 10, 10};

// Sound FX
AudioPlayMemory    sound1;
AudioMixer4        mix1;    // two 4-channel mixers are needed in
AudioMixer4        mix2;    // tandem to combine 6 audio sources
AudioOutputI2S     headphones;
AudioConnection c8(mix1, 0, headphones, 0);
AudioConnection c9(mix1, 0, headphones, 1);
AudioConnection c1(sound1, 0, mix1, 0);
AudioControlSGTL5000 audioShield;

ILI9341_t3n tft = ILI9341_t3n(TFT_CS, TFT_DC, TFT_RST);

void drawTitleScreen();
void drawRulesScreen();
void startGame(int startLevel);
void drawPaused();
void erasePaused();
void drawGameOver();
void wipeGameArea();
void playShotSound();
void playExplosionSound();
void playRefuelSound();
void playTickSound();
void playWarpSound();
void drawExplosion(int x, int y, int maxRadius);
void initShots();
void loadLevelData(const int levelData[]);
void loadLevel(int lvl);
void drawGround();
void drawHeader();
void drawPlayerFuel();
void changePlayerFuel(int changeAmt);
void changePlayerScore(int changeAmt);
void drawPlayerLives();
void drawFuelPacks();
void drawFuelPack(int x, int y);
void eraseFuelPack(int x, int y);
void drawTurrets(int shotRate);
void drawTurret(int x, int y, int direction);
void eraseTurret(int x, int y, int direction);
void drawShip(int ctrX, int ctrY, double rotation, bool thrust);
void eraseShip();
void createPlayerShot(int x, int y, double rotation);
void movePlayerShots();
void movePlayerShot(int idx);
void createTurretShot(int x, int y);
bool moveTurretShots();
bool moveTurretShot(int idx);
bool hitsPlayer(int x, int y, double tolerance);
int  checkFuelHit(int x, int y, double tolerance);
bool hitsFuel(int idx, int x, int y, double tolerance);
int  checkTurretHit(int x, int y, double tolerance);
bool hitsTurret(int idx, int x, int y, double tolerance);
bool hitsGround(int x, int y, double tolerance);
bool hitsLine(int x, int y, int lineX1, int lineY1, int lineX2, int lineY2, double tolerance);
void startPlayer();
void killPlayer();
void advanceLevel();
void checkButtonPresses();
void checkJoystick();
void handleTitle();
void handleRules();
void handlePlaying();
void handlePaused();
void handleGameOver();


/*
 *  Initialize hardware, peripherals, and libraries
 */
void setup() 
{
  Serial.begin(9600);
  Serial.println("Teensy R4ge Pro - Gravitack"); 
  delay(100);

  Serial.print("Setting up pins..."); 

  // Set up the buttons
  pinMode(BTN_A, INPUT_PULLUP);
  pinMode(BTN_B, INPUT_PULLUP);
  pinMode(BTN_X, INPUT_PULLUP);
  pinMode(BTN_Y, INPUT_PULLUP);
  pinMode(BTN_UP, INPUT_PULLUP);
  pinMode(BTN_DOWN, INPUT_PULLUP);
  pinMode(BTN_LEFT, INPUT_PULLUP);
  pinMode(BTN_RIGHT, INPUT_PULLUP);
  
  // Set up the joystick
  pinMode(JOYX, INPUT);
  pinMode(JOYY, INPUT);
  pinMode(JBTN, INPUT_PULLUP);

  // Set up the rotary encoder knob
  pinMode(ENC_1, INPUT);
  pinMode(ENC_2, INPUT);
  pinMode(ENC_BTN, INPUT_PULLUP);
  delay(100);
  
  // Set up the TFT and touch screen
  Serial.print("Setting display..."); 
  tft.begin();
  tft.setRotation(SCREEN_ROT);
  tft.fillScreen(ILI9341_BLACK);
  Serial.println("done"); 

  Serial.print("Setting audio..."); 

  AudioMemory(10);
  audioShield.enable();
  audioShield.volume(0.5);

  Serial.println("done"); 

  drawTitleScreen();
}

/*
 * Draws the game title/splash screen
 */
void drawTitleScreen()
{
  tft.fillScreen(ILI9341_BLACK);

  tft.writeRect(20, 60, 279, 77, (uint16_t *)gravitack_title);
  
  tft.setTextSize(2);
  tft.setTextColor(ILI9341_WHITE);
  tft.setCursor(40, 200);
  tft.print("[X] RULES, [Y] START");

  game_state = STATE_TITLE;
}

/*
 * Draws the game instructions screen
 */
void drawRulesScreen()
{
  tft.fillScreen(ILI9341_BLACK);
  
  tft.setTextSize(2);
  tft.setTextColor(ILI9341_WHITE);
  tft.setCursor(50, 0);
  tft.print("CONTROLS & SCORING");

  tft.drawLine(0, 25, 320, 25, ILI9341_GREEN);

  tft.setTextColor(ILI9341_DARKGREY);
  tft.setTextSize(2);
  tft.setCursor(10, 40);
  tft.print("Thrust: [A]");

  tft.setCursor(190, 40);
  tft.print("Pause: [X]");
  
  tft.setCursor(10, 60);
  tft.print("Fire:   [B]");
  
  
  tft.drawRect(24, 100, FUEL_WD, FUEL_HT, ILI9341_CYAN);
  
  tft.setCursor(50, 100);
  tft.print("200 pts");

  tft.setTextSize(1);
  tft.setCursor(160, 100);
  tft.print("Touch fuel packs with your");
  tft.setCursor(160, 110);
  tft.print("ship to pick them up");
  
  drawTurret(15, 140, 1);

  tft.setTextSize(2);
  tft.setCursor(50, 135);
  tft.print("500 pts"); 

  tft.setTextSize(1);
  tft.setCursor(160, 145);
  tft.print("Shoot all turrets");
  
  tft.setCursor(50, 165);
  tft.print("Pick up all fuel packs and destroy all");
  tft.setCursor(50, 175);
  tft.print("turrets to advance to the next level.");
  tft.setCursor(50, 190);
  tft.print("** Free ship every 10,000 points **");

  tft.drawLine(0, 210, 320, 210, ILI9341_GREEN);

  tft.setTextColor(ILI9341_WHITE);
  tft.setTextSize(2);
  tft.setCursor(60, 220);
  tft.print("PRESS [Y] TO START");
  
  game_state = STATE_RULES;
}

/*
 * Initializes the game variables and draws the main gameplay screen
 */
void startGame(int startLevel)
{
  tft.fillScreen(ILI9341_BLACK);

  level = startLevel;
  player_score = 0;
  player_lives = 4;
  player_shot_range = 100;
  next_ship = 10000;
  turret_range = 10;

  loadLevel(level);
  drawHeader();
  drawGround();
  drawShip(player_ctr_x, player_ctr_y, player_rotation, false);

  game_state = STATE_PLAYING;
}

/*
 * Draws a Paused message on the screen
 */
void drawPaused()
{
  tft.fillRect(110, 20, 112, 20, ILI9341_BLACK);
  tft.setTextSize(1);
  tft.setTextColor(ILI9341_RED);
  tft.setCursor(110, 20);
  tft.print("** PAUSED **");
  delay(200);
  
  game_state = STATE_PAUSED;
}

/*
 * Erases the Paused message
 */
void erasePaused()
{
  tft.fillRect(110, 20, 112, 20, ILI9341_BLACK);
  delay(200);
  
  game_state = STATE_PLAYING;
}

/*
 * Draws the Game Over screen
 */
void drawGameOver()
{
  drawHeader();
  drawGround();
  tft.fillRect (80, 70, 160, 55, ILI9341_BLACK);  // clear msg area
  tft.drawRect (80, 70, 160, 55, ILI9341_YELLOW); // border
  
  tft.setTextSize(2);
  tft.setTextColor(ILI9341_WHITE);
  tft.setCursor(105, 80);
  tft.print("GAME OVER");

  tft.setTextSize(1);
  tft.setTextColor(ILI9341_WHITE);
  tft.setCursor(105, 110);
  tft.print("PRESS [Y] TO START");

  game_state = STATE_GAME_OVER;
}

/*
 * Draws the wipe effect used when moving to the next level
 */
void wipeGameArea()
{
  playWarpSound();
  for (int i = 0; i <= 110; i++)
  {
    tft.drawRect(110 - i, 130 - i, i * 2 + 100, i * 2, ILI9341_WHITE);
    delay(10);
  }
  for (int i = 0; i <= 110; i++)
  {
    tft.drawRect(110 - i, 130 - i, i * 2 + 100, i * 2, ILI9341_BLACK);
    delay(10);
  }
}

/*
 * Plays the player shot sound
 */
void playShotSound()
{
  sound1.stop();
  sound1.play(fire_wav);
}

/*
 * Plays the explosion sound
 */
void playExplosionSound()
{
  sound1.stop();
  sound1.play(explosion_wav);
}

/* 
 *  Plays the fuel pickup sound 
 */
void playRefuelSound()
{
  sound1.stop();
  sound1.play(refuel_wav);
}

/* 
 *  Plays the tick sound 
 */
void playTickSound()
{
  sound1.stop();
  sound1.play(tick_wav);
}

/* 
 *  Plays the level warp sound 
 */
void playWarpSound()
{
  sound1.stop();
  sound1.play(warp_wav);
}


/*
 * Draws and plays an explosion sound for a turret or the player ship
 */
void drawExplosion(int x, int y, int maxRadius)
{
  playExplosionSound();
  for (int i = 1; i <= maxRadius; i++)
  {
    tft.drawCircle(x, y, i, ILI9341_YELLOW);
    delay(10);
  }
  for (int i = 1; i <= maxRadius; i++)
  {
    tft.drawCircle(x, y, i, ILI9341_BLACK);
    delay(10);
  }
}

/*
 * Initializes the player and turret shots to inactive
 */
void initShots()
{
  for (int i = 0; i < MAX_SHOTS; i++)
  {
    if (shot_range[i])  // erase old active shot
      tft.drawRect(shot_x[i], shot_y[i], 2, 2, ILI9341_BLACK);
    
    shot_range[i] = 0;
  }

  for (int i = 0; i < MAX_TURRET; i++)
  {
    if (turret_shot_range[i])  // erase old active turret shot
      tft.drawRect(turret_shot_x[i], turret_shot_y[i], 2, 2, ILI9341_BLACK);
    
    turret_shot_range[i] = 0;
  }
}

/*
 * Initializes game level (ground, fuel packs, turrets) from the level data parameter
 */
void loadLevelData(const int levelData[])
{
  // Load the ground segment data
  for (int i = 0; i < MAX_GROUND; i++)
   {
     if (levelData[i * 2] < 999)
     {
      ground_x[i] = levelData[i * 2];
      ground_y[i] = levelData[i * 2 + 1];
      ground_size = i;
     }
   }
   
   // Load the fuel pack location data
   int fuel_start = MAX_GROUND * 2;
   fuel_count = 0;
   
   for (int i = 0; i < MAX_FUEL; i++)
   {
     if (levelData[fuel_start + i * 2] < 999)
     {
      fuel_x[i] = levelData[fuel_start + i * 2];
      fuel_y[i] = levelData[fuel_start + i * 2 + 1];
      fuel_active[i] = true;
      fuel_count += 1;
     }
     else
     {
       fuel_active[i] = false;
     }
   }
   fuel_remaining = fuel_count;
  
   // Load the enemy turret location data
   int turret_start = fuel_start + MAX_FUEL * 2;
   turret_count = 0;
   
   for (int i = 0; i < MAX_TURRET; i++)
   {
     if (levelData[turret_start + i * 3] < 999)
     {
      turret_x[i] = levelData[turret_start + i * 3];
      turret_y[i] = levelData[turret_start + i * 3 + 1];
      turret_dir[i] = levelData[turret_start + i * 3 + 2];
      turret_active[i] = true;
      turret_count += 1;
     }
     else
     {
       turret_active[i] = false;
     }
   }
   turret_remaining = turret_count;
   
   // Load the miscellanous player/level data
   int misc_start = turret_start + MAX_TURRET * 3;
   
   player_start_x = levelData[misc_start];
   player_start_y = levelData[misc_start + 1];
   level_delay = levelData[misc_start + 2];
   
   startPlayer();
}

/*
 * Initializes game level (ground, fuel packs, turrets) based on the level parameter
 */
void loadLevel(int lvl)
{
  int level_map = lvl;
  while (level_map > MAX_LEVEL)
  {
    level_map -= MAX_LEVEL;
  }
  
  switch(level_map)
  {
  case 1: loadLevelData((int *)Level_01);
    break;
  case 2: loadLevelData((int *)Level_02);
    break;
  case 3: loadLevelData((int *)Level_03);
    break;
  case 4: loadLevelData((int *)Level_04);
    break;
  case 5: loadLevelData((int *)Level_05);
    break;
  case 6: loadLevelData((int *)Level_06);
    break;
  default:  loadLevelData((int *)Level_01);
  }
  
  tft.fillRect(0, 10, 320, 240, ILI9341_BLACK);
}

/*
 * Draws the ground segments for the current level
 */
void drawGround()
{
  for (int i = 0; i < ground_size; i++)
  {
  if (ground_x[i] < INVALID_ITEM && ground_x[i+1] < INVALID_ITEM)
  {
    tft.drawLine(ground_x[i], ground_y[i], ground_x[i+1], ground_y[i+1], ILI9341_GREEN);
  }
  }
}

/*
 * Draws the game header at the top of the screen (fuel, lives, score)
 */
void drawHeader()
{
  tft.setTextSize(1);
  tft.setTextColor(ILI9341_WHITE);
  
  tft.setCursor(0, 1);
  tft.print("FUEL");
  drawPlayerFuel();

  drawPlayerLives();

  tft.setCursor(240, 0);
  tft.print("SCORE: 000000");
  changePlayerScore(0);  
}

/*
 * Draws the player fuel bar
 */
void drawPlayerFuel()
{
  tft.drawRect(PLAYER_FUEL_X - 1, 0, 103, 10, ILI9341_WHITE);
  tft.fillRect(PLAYER_FUEL_X, 1, player_fuel, 8, ILI9341_CYAN);
}

/*
 * Changes the player fuel by the given amount and redraws the fuel bar in the game header
 */
void changePlayerFuel(int changeAmt)
{
  if (changeAmt < 0)
  {
    tft.fillRect(PLAYER_FUEL_X + player_fuel, 1, changeAmt, 8, ILI9341_BLACK); 
    player_fuel += changeAmt;
    return;
  }

  // avoid going over fuel limit
  int chg = changeAmt;
  if (chg + player_fuel > 100)
    chg = 100 - player_fuel;

  tft.fillRect(PLAYER_FUEL_X + player_fuel, 1, chg, 8, ILI9341_CYAN); 
  player_fuel += chg;
  return;
}

/*
 * Changes and displays the player score and awards any free ships
 */
void changePlayerScore(int changeAmt)
{
  player_score += changeAmt;

  tft.fillRect(280,0, 40, 10, ILI9341_BLACK); // erase prev score
  tft.setTextColor(ILI9341_WHITE);
  tft.setCursor(280, 0);
  tft.print(player_score);
  
  if (changeAmt > 0 && player_score >= next_ship)
  {
    player_lives += 1;
    next_ship += 10000;
    drawPlayerLives();
  }
}

/*
 * Draws the player lives remaining in the game header
 */
void drawPlayerLives()
{
    int ctr_x = 0, ctr_y = 0;
    int x[5], y[5];
    
    for (int i = 0; i < MAX_LIVES; i++)
    {
      if (i < player_lives)
      {
        ctr_x = 150 + i * 16;
        ctr_y = 9;
        
        // nose of ship
        x[0] = ctr_x + cos(PIx15) * SHIP_SIZE;
        y[0] = ctr_y + sin(PIx15) * SHIP_SIZE;
        // left wingtip
        x[1] = ctr_x + cos(PIx15 - PId15) * SHIP_SIZE;
        y[1] = ctr_y + sin(PIx15 - PId15) * SHIP_SIZE;
        //center point
        x[2] = ctr_x;
        y[2] = ctr_y;
        // right wingtip
        x[3] = ctr_x + cos(PIx15 + PId15) * SHIP_SIZE;
        y[3] = ctr_y + sin(PIx15 + PId15) * SHIP_SIZE;
        // nose of ship
        x[4] = x[0];
        y[4] = y[0];
  
        // connect ship vertices
        for(int i = 0; i < 4; i++)
        {
          tft.drawLine(x[i], y[i], x[i+1], y[i+1], ILI9341_BLUE);
        }
      }
      else
      {
        // blank out ship space
        tft.fillRect(ctr_x - SHIP_SIZE, 0, 16, 16, ILI9341_BLACK);
      }
    }
}

/*
 * Draws the fuel packs on the game screen
 */
void drawFuelPacks()
{
  for (int i = 0; i < fuel_count; i++)
  {
    if (fuel_active[i])
    {
      drawFuelPack(fuel_x[i], fuel_y[i]);
    }
  }
}

/*
 * Draws a fuel pack at the given x,y coordinate (top left corner)
 */
void drawFuelPack(int x, int y)
{
  tft.drawRect(x, y, FUEL_WD, FUEL_HT, ILI9341_CYAN);
}

/*
 * Erases a fuel pack at the given x,y coordinate (top left corner)
 */
void eraseFuelPack(int x, int y)
{
  tft.drawRect(x, y, FUEL_WD, FUEL_HT, ILI9341_BLACK);
}

/*
 * Draws all turrets and randomly shoots at the player based on the shotRate
 */
void drawTurrets(int shotRate)
{
  int x, y;
  
  for (int i = 0; i < turret_count; i++)
  {
    if (turret_active[i])
    {
      drawTurret(turret_x[i], turret_y[i], turret_dir[i]);
      
      if (shotRate > random(100))
      {
        // try to shoot (from tip of turret)
        x = turret_x[i] + turret_offset_x[turret_dir[i] - 1];
        y = turret_y[i] + turret_offset_y[turret_dir[i] - 1];
        createTurretShot(x, y);
      }
    }
  }
}

/*
 * Draws a turret at the given x,y coordinates
 */
void drawTurret(int x, int y, int direction)
{
  switch(direction)
  {
  case DIR_UP: 
    tft.drawRect(x, y, 20, 10, ILI9341_RED);
    tft.drawRect(x + 5, y - 10, 10, 10, ILI9341_RED);
    break;
  case DIR_DOWN:
    tft.drawRect(x, y, 20, 10, ILI9341_RED);
    tft.drawRect(x + 5, y + 10, 10, 10, ILI9341_RED);
    break;
  case DIR_LEFT:
    tft.drawRect(x, y, 10, 20, ILI9341_RED);
    tft.drawRect(x - 10, y + 5, 10, 10, ILI9341_RED);
    break;
  case DIR_RIGHT:
    tft.drawRect(x, y, 10, 20, ILI9341_RED);
    tft.drawRect(x + 10, y + 5, 10, 10, ILI9341_RED);
    break;
  default:
    tft.drawRect(x, y, 20, 20, ILI9341_RED); // headless
  }
}
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
void loop() 
{
  checkButtonPresses();
  checkJoystick();

  switch(game_state)
  {
    case STATE_TITLE:
      handleTitle(); 
      break;
    case STATE_RULES:
      handleRules();
      break;
    case STATE_PLAYING:
      handlePlaying();
      break;
    case STATE_PAUSED:
      handlePaused(); 
      break;
    case STATE_GAME_OVER:
      handleGameOver(); 
      break;
    
  }

  delay(level_delay);
}

/*
 * Handles the STATE_TITLE game state logic 
 */
void handleTitle()
{
  if (btnX_released)
  {
    drawRulesScreen();
    return;
  }

  if (btnY_released)
  {
    startGame(1);
    return;
  }

  // secret start level hack
  if (btnA_pressed)
  {
    //left = bit 0, up = bit 1, down = bit 2, righ = bit 3
    int startLevel = (btnLeft_pressed ? 1 : 0) + (btnUp_pressed ? 2 : 0) + (btnDown_pressed ? 4 : 0) + (btnRight_pressed ? 8 : 0); 
    startGame(startLevel);
  }
}

/*
 * Handles the STATE_RULES game state logic
 */
void handleRules()
{
  if (btnY_released)
  {
    startGame(1);
  }
}

/*
 * Handles the STATE_PLAYING game state logic
 */
void handlePlaying()
{
  // player controls logic
  if (btnX_released)
  {
    drawPaused();
    return;
  }
  
  if (btnLeft_pressed)
  {
    player_rotation -= 0.1;
  }

  if (btnRight_pressed)
  {
    player_rotation += 0.1;
  }
  
  player_speed_y += gravity;

  if (btnA_pressed)
  {
    if (player_fuel > 0)
    {
      player_speed_x += sin(player_rotation + PId2) / 8;
      player_speed_y -= cos(player_rotation + PId2) / 8;
      changePlayerFuel(-1);
    }
  }

  player_ctr_x += player_speed_x;
  player_ctr_y += player_speed_y;

  // screen bounds checking
  if ((player_ctr_x > SCREEN_WD - SHIP_SIZE && player_speed_x > 0) || 
      (player_ctr_x < SHIP_SIZE && player_speed_x < 0))
  {
    player_speed_x = -player_speed_x;
    player_ctr_x += player_speed_x;
  }

  if (((player_ctr_y > (SCREEN_HT - SHIP_SIZE)) && (player_speed_y > 0)) || 
      (player_ctr_y <  20 && (player_speed_y < 0)))
  {
    player_speed_y = -player_speed_y;
    player_ctr_y += player_speed_y;
  }

  if (btnB_pressed && !btnB_was_pressed)
  {
    createPlayerShot(player_ctr_x, player_ctr_y, player_rotation);
  }

  // game object hit detection and updates/animation
  drawGround();
  drawFuelPacks();
  drawTurrets(2);
  moveTurretShots();
  if (game_state != STATE_PLAYING)  // in case player died
    return;
    
  if (checkFuelHit(player_ctr_x, player_ctr_y, SHIP_SIZE) >= 0)
  {
    changePlayerScore(200);
    changePlayerFuel(50); 
    fuel_remaining -= 1;
  }

  // check the ship vertices for ground collision
  if (hitsGround(player_ctr_x, player_ctr_y, SHIP_SIZE - 2))
  {
    killPlayer();
    return;
  }

  // check the ship vertices for ground collision
  // this is more accurate, though slower - especially with more ground segments
  for(int i = 0; i < 4; i++)
  {
    if (hitsGround(ship_x[i], ship_y[i], 1))
    {
      killPlayer();
      return;
    }
  }
  
  eraseShip();
  drawShip(player_ctr_x, player_ctr_y, player_rotation, btnA_pressed && player_fuel > 0);

  movePlayerShots();

  if (turret_remaining == 0 && fuel_remaining == 0)
  {
    advanceLevel();
  }
}

/*
 * Handles the STATE_PAUSED game state logic
 */
void handlePaused()
{
  if (btnX_released)
  {
   erasePaused();
  }
}

/*
 * Handles the STATE_GAME_OVER game state logic
 */
void handleGameOver()
{
  if (btnY_released)
  {
    drawTitleScreen();
  }
}

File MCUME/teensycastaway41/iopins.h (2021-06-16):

#ifndef IOPINS_H
#define IOPINS_H

#include "platform_config.h"

#ifndef OLD_LAYOUT

#define TFT_SCLK        13
#define TFT_MOSI        11
#define TFT_MISO        12
#define TFT_TOUCH_CS    255
#define TFT_TOUCH_INT   255
#define TFT_DC          9
#define TFT_CS          10 // 255 for LORES ST7789 (NO CS)
#define TFT_RST         255 // 255 for ILI/ST if connected to 3.3V

// PSRAM
#define PSRAM_CS      36
#define PSRAM_MOSI    35
#define PSRAM_MISO    34
#define PSRAM_SCLK    37

// SD
#define SD_SCLK        13
#define SD_MOSI        12
#define SD_MISO        11 
#ifdef EXTERNAL_SD
#define SD_CS          8
#else
#define SD_CS          BUILTIN_SDCARD
#endif 

// I2C keyboard
#define I2C_SCL_IO     19
#define I2C_SDA_IO     18

// Analog joystick (primary) for JOY2 and 5 extra buttons
#ifdef HAS_T4_VGA
#define PIN_JOY2_A1X    A3
#define PIN_JOY2_A2Y    A2
#define PIN_JOY2_BTN    14
#define PIN_KEY_USER1   22
#define PIN_KEY_USER2   23

// Second joystick
#define PIN_JOY1_BTN     34
#define PIN_JOY1_1       35 // UP
#define PIN_JOY1_2       36 // DOWN
#define PIN_JOY1_3       38 // RIGHT
#define PIN_JOY1_4       37 // LEFT

#else
#define PIN_JOY2_A1X    16
#define PIN_JOY2_A2Y    17
#define PIN_JOY2_BTN    25
#define PIN_KEY_USER1   2 // BTN A
#define PIN_KEY_USER2   3 // BTA B
#define PIN_KEY_USER3   4 // BTN X
#define PIN_KEY_USER4   5 // BTN Y

// Second joystick
#define PIN_JOY1_BTN     24
#define PIN_JOY1_1       29  // UP
#define PIN_JOY1_2       30  // DOWN
#define PIN_JOY1_3       32  // RIGHT
#define PIN_JOY1_4       31  // LEFT
#endif

#else 
// OLD LAYOUT!!!!

#define HAS_VGA 1

// ILI9341
#define TFT_SCLK        13
#define TFT_MOSI        11
#define TFT_MISO        12
#define TFT_TOUCH_CS    38
#define TFT_TOUCH_INT   37
#define TFT_DC          9
#define TFT_CS          10
#define TFT_RST         255  //connected to 3.3V

// I2C keyboard
#define I2C_SCL_IO      3
#define I2C_SDA_IO      4

// Analog joystick (primary) for JOY2 and 5 extra buttons
#define PIN_JOY2_A1X    A12
#define PIN_JOY2_A2Y    A13
#define PIN_JOY2_BTN    36
#define PIN_KEY_USER1   35
#define PIN_KEY_USER2   34
#define PIN_KEY_USER3   33
#define PIN_KEY_USER4   39

// Second joystick
#define PIN_JOY1_BTN     30
#define PIN_JOY1_1       16
#define PIN_JOY1_2       17
#define PIN_JOY1_3       18
#define PIN_JOY1_4       19
#endif

#endif

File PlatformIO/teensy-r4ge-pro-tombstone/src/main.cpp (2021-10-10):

/***************************************************
* "Tombstone City: 21st Century" game
* An emulation of the classic TI-99/4A game by John Plaster for Texas Instruments 
* *
* Requires:
* - Teensy R4ge Pro v2
* - Teensy 4.1 board

Copyright (c) 2021 Paul Pagel
This is free software; see the license.txt file for more information.
There is no warranty; not even for merchantability or fitness for a particular purpose.
****************************************************/

#include "SD.h"
#include <SPI.h>
#include <ILI9341_t3n.h>
#include <Audio.h>
#include "teensy_r4ge_pro.h"

#include "explosion_wav.h"
#include "fire_wav.h"
#include "life_wav.h"
#include "theme_wav.h"
#include "Tombstone_title.h" 
#include "Tiles.h" 

// ---- Game Settings and Variables ----

#define DIRT_COLOR  0xFEF1
#define BROWN_COLOR 0x7980

#define TILE_SIZE      10
#define TITLE_HT       30
#define TITLE_WD       280
#define BORDER_TOP     10
#define BORDER_LEFT    20
#define BORDER_BOTTOM  SCREEN_HT - 10
#define BORDER_RIGHT   SCREEN_WD - 20
#define STATUS_TOP     GAME_BOTTOM  //BORDER_BOTTOM - 20
#define STATUS_HT      20
#define GAME_ROWS      17
#define GAME_COLS      28
#define GAME_TOP       BORDER_TOP + TITLE_HT
#define GAME_LEFT      BORDER_LEFT
#define GAME_BOTTOM    GAME_TOP + GAME_ROWS * TILE_SIZE
#define GAME_RIGHT     GAME_LEFT + GAME_COLS * TILE_SIZE
#define GAME_HT        GAME_BOTTOM - GAME_TOP
#define GAME_WD        GAME_RIGHT - GAME_LEFT
#define MAX_SPEED      20  // for morg or tumbleweed movement, higher value makes game easier

enum tile_type {
  TILE_UNKNOWN,
  TILE_EMPTY,
  TILE_PLAYER,
  TILE_SHOT,
  TILE_BLOCK,
  TILE_CACTUS,
  TILE_CACTUS_ACTIVE,
  TILE_TUMBLEWEED,
  TILE_MORG,
  TILE_EXPLOSION
};

enum game_state_type {
  STATE_TITLE,
  STATE_RULES,
  STATE_PLAYING,
  STATE_PAUSED,
  STATE_GAME_OVER
};

enum direction_type {
  DIR_UP,
  DIR_DOWN,
  DIR_LEFT,
  DIR_RIGHT
};

enum     game_state_type game_state;
int      difficulty, day, population, schooners;
uint8_t  player_row, player_col, player_dir;
uint8_t  shot_row, shot_col;
int      shot_row_chg, shot_col_chg;
bool     shot_active, shot_is_new;
uint8_t  game_grid[GAME_ROWS * GAME_COLS];
uint16_t spawn_counter, spawn_signal, spawn_max;
int      spawn_row, spawn_col;
uint8_t  morg_speed, tumbleweed_speed;

bool btnA_pressed, btnB_pressed, btnX_pressed, btnY_pressed;
bool btnUp_pressed, btnDown_pressed, btnLeft_pressed, btnRight_pressed;
bool btnA_was_pressed, btnB_was_pressed, btnX_was_pressed, btnY_was_pressed;
bool btnUp_was_pressed, btnDown_was_pressed, btnLeft_was_pressed, btnRight_was_pressed;
bool btnA_released, btnB_released, btnX_released, btnY_released;
bool btnUp_released, btnDown_released, btnLeft_released, btnRight_released;
bool joy_pressed, knob_pressed; 

int16_t joy_x, joy_y; 

// Sound FX
AudioPlayMemory    sound1;
AudioMixer4        mix1;    // two 4-channel mixers are needed in
AudioMixer4        mix2;    // tandem to combine 6 audio sources
AudioOutputI2S     headphones;
AudioConnection c8(mix1, 0, headphones, 0);
AudioConnection c9(mix1, 0, headphones, 1);
AudioConnection c1(sound1, 0, mix1, 0);
AudioControlSGTL5000 audioShield;

ILI9341_t3n tft = ILI9341_t3n(TFT_CS, TFT_DC, TFT_RST);

// ---- Function Prototypes ----
void    setup(); 
void    drawBackground();
void    drawTitleScreen();
void    drawRulesScreen();
void    drawGameScreen();
void    drawDay();
void    drawPopulation();
void    drawSchooners();
void    drawPaused();
void    erasePaused();
void    drawGameOver();
void    drawCity(bool active);
void    drawPlayer();
void    movePlayer(uint8_t moveDirection, int rowChg, int colChg);
void    moveMorg(int gridIndex);
void    moveTumbleweed(int gridIndex);
void    doMovement();
int     getNeighborTile(int row, int col, uint8_t tile, bool allowInCity);
int     getNeighborTileEx(int row, int col, uint8_t tile, bool allowInCity, int excludeRow, int excludeCol);
void    spawnMorg();
void    prepareSpawn();
void    doSpawning();
int     getSpawnCount();
void    checkCactusTriplet(int row, int col);
void    playShot();
void    playExplosion();
void    playTeleport();
void    playNextDaySong();
void    playThemeSong();
void    killPlayer();
void    playerShoot();
void    playerPanic();
void    moveShot();
void    addCacti(uint8_t count);
void    addSpawnCacti(uint8_t count);
void    addTumbleweeds(uint8_t count);
void    addMorgs(uint8_t count);
bool    isOutOfBounds(int row, int col);
bool    isInBounds(int row, int col, bool allowInCity);
bool    isInCity(int row, int col);
bool    isOccupied(int row, int col);
uint8_t getGridIndex(int row, int col);
uint8_t getTileType(int row, int col);
void    setTileType(int row, int col, uint8_t tile, bool draw);
void    setTextColor(uint16_t color, bool inverted);
void    initGame();
void    playerStart();
void    advanceDay();
void    checkButtonPresses();
void    checkJoysticks();
void    delayAudio(long ms);
void    loop(void);
void    handleTitle();
void    handleRules();
void    handlePlaying();
void    handlePaused();
void    handleGameOver();

/*
 * Initialize the board hardware and software on startup
 */
void setup() 
{
  Serial.begin(9600);
  Serial.println("\nTeensy R4ge Pro - Tombstone City"); 
  delay(100);

  Serial.print("Setting up pins..."); 

  // Set up the buttons
  pinMode(BTN_A, INPUT_PULLUP);
  pinMode(BTN_B, INPUT_PULLUP);
  pinMode(BTN_X, INPUT_PULLUP);
  pinMode(BTN_Y, INPUT_PULLUP);
  pinMode(BTN_UP, INPUT_PULLUP);
  pinMode(BTN_DOWN, INPUT_PULLUP);
  pinMode(BTN_LEFT, INPUT_PULLUP);
  pinMode(BTN_RIGHT, INPUT_PULLUP);
  
  // Set up the joystick
  pinMode(JOYX, INPUT);
  pinMode(JOYY, INPUT);
  pinMode(JBTN, INPUT_PULLUP);

  // Set up the rotary encoder knob
  pinMode(ENC_1, INPUT);
  pinMode(ENC_2, INPUT);
  pinMode(ENC_BTN, INPUT_PULLUP);
  delay(100);
  
  // Set up the TFT and touch screen
  Serial.print("Setting display..."); 
  tft.begin();
  tft.setRotation(SCREEN_ROT);
  tft.fillScreen(ILI9341_BLACK);
  Serial.println("done"); 

  Serial.print("Setting audio..."); 

  AudioMemory(10);
  audioShield.enable();
  audioShield.volume(0.5);

  Serial.println("done"); 

  initGame();
  drawBackground();
  drawTitleScreen();
}

/*
 * Draws the dirt-colored background used in the game other screens
 */
void drawBackground()
{
  tft.fillScreen(BROWN_COLOR);
  tft.writeRect(BORDER_LEFT, BORDER_TOP, TITLE_WD, TITLE_HT, (uint16_t *)tombstone_title);
}

/*
 * Displays the title/options screen
 */
void drawTitleScreen()
{
  tft.fillRect(GAME_LEFT, GAME_TOP, GAME_WD, GAME_HT + STATUS_HT, DIRT_COLOR);
  
  tft.setTextColor(ILI9341_BLACK);  
  tft.setTextSize(2);
  tft.setCursor(40, 80);
  tft.print("[A] LEVEL 1 = NOVICE");
  tft.setCursor(40, 100);
  tft.print("[B] LEVEL 2 = MASTER");
  tft.setCursor(40, 120);
  tft.print("[X] LEVEL 3 = INSANE");

  tft.setCursor(90, 160);
  tft.print("YOUR CHOICE?");

  tft.setCursor(44, 200);
  tft.print("PRESS [Y] FOR RULES");

  game_state = STATE_TITLE;
}
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

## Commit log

2021-05-31 Test sketch and initial docs
    [Rage_Pro_Case3.stl, TeensyR4gePro-v2_bom_2.ods]
2021-06-01 Update BOM
    [TeensyR4gePro-v2_bom_2.ods]
2021-06-12 Add Gerbers
    [TeensyR4gePro-v2-B_Cu.gbr, TeensyR4gePro-v2-B_Mask.gbr, TeensyR4gePro-v2-B_Paste.gbr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]
2021-11-26 Add assembly slide deck
2021-11-27 Add ArduinoIDE test
2024-01-14 Add BOM CSV
    [TeensyR4gePro-v2_bom_2.csv]
